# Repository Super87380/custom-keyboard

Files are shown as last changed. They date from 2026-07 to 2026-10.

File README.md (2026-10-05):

# Custom 75% Mechanical Keyboard

This is a custom 75% mechanical keyboard with 3 macro keys that I designed every part for, from the PCB to the firmware.

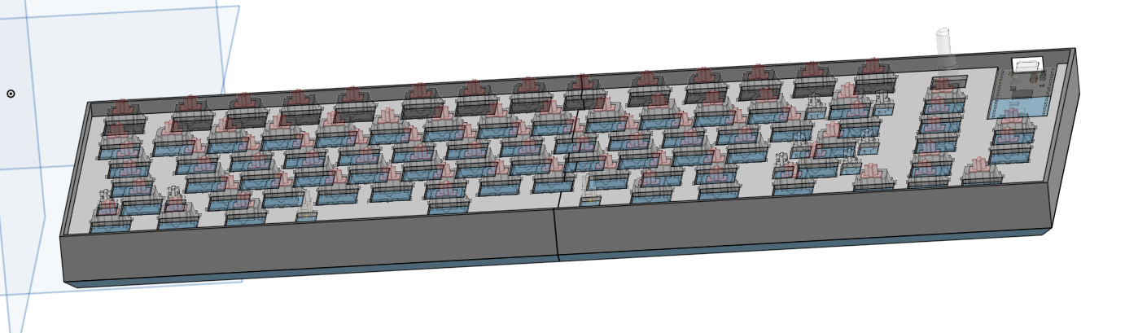
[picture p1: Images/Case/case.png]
Case


## Why I Built it
A while before finding out about Hack Club I wanted to make my own mechanical keyboard. After finding out how much it would cost I got de motivated and gave up on the idea.
Later I was watching YouTube when the creator mentioned Hack Club and how they help teenagers get experience in engineering. I was looking through the programs running when I saw KEEB.
With the opportunity to get the keyboard funded by Hack Club/KEEB it was the perfect chance for me to make the keyboard I had wanted to before.

## Features
- 3 Macro keys
- Rotary Encoder with a switch
- RGB back lighting
- Vast firmware support - the firmware I made uses KMK

## Designing
I started this project by brainstorming ideas for different layouts, sizes, and features. My original idea was a 75% keyboard with a screen, 1 macro key, and a rotary encoder. The idea soon evolved into what it is now.
After brainstorming I used [keyboard layout editor](https://www.keyboard-layout-editor.com/) and [photopea](https://www.photopea.com/) to design the layout and matrix wiring digitally.
I then made the first schematic and PCB in KiCad with a screen and 1 macro key. After I finished the schematic and PCB I realized I wanted to add backlighting for late night gaming/programming sessions and more macro keys, so I added sk6812 mini-e LED's under each switch and removed the screen for 2 more macro keys. After I finished with the electronics I designed a case and plate in Onshape, I found this pretty challenging as it was my first time using Onshape; I can definitely improve the case a lot. I then made the firmware, I chose to sue KMK because I have more expierence with python and have made a macropad with KMK already.

## What I Found Difficult
- LED wiring, especially because I didnt originally route with them in minde
- Modeling the case and plate in Onshape
- Sourcing cheap components with cheap shipping

## What I Learned
- Modelling in Onshape
- Better PCB design
- How mechanical keyboards work
- Reading data sheets and applying what I read
- Layers in KMK
- RGB in KMK




## BOM
| Sl No. | Name | Notes | Quantity | Price Per Unit | Cost | Shipping | Link |
| :---: | :--- | :--- | :---: | :---: | :---: | :---: | :--- |
| 1 | PCB | Manufactured by JLCPBC (minimum 5) (order through JLclone desktop app (saves money)) | 1 | — | $25.40 | $15.96 | [JLCPCB](JLCPCB) |
| 2 | Diode | Diodes to prevent ghosting (part num: 1N41481N4148-T26A) | 84 | $0.0536 | $4.50 | $5.00 | [DigiKey](https://www.digikey.ca/en/products/detail/onsemi/1N4148-T26A/978507) |
| 3 | Resistor | For start and end of LED data signals | 2 | $0.16 | $0.32 | $5.00 | [DigiKey](https://www.digikey.ca/en/products/detail/yageo/RC0805FR-07560RL/728036) |
| 4 | Capacitor | Decoupling capacitors for LED's | 83 | $0.05 | $4.15 | $5.00 | [DigiKey](https://www.digikey.ca/en/products/detail/yageo/CC0603KRX7R7BB104/302822) |
| 5 | LED | LED's for backglow of the keyboard (order in multiples of 5) | 85 | $0.089647 | $7.62 | $15.14 | [LCSC](https://www.lcsc.com/product-detail/C5149201.html?s_z=n_SK6812%2520MINI-E) |
| 6 | Raspberry Pi Pico W (with headers) | The microcontroller for the keyboard (already owned) | 1 | $0.00 | $0.00 | $0.00 | [PiShop](https://www.pishop.ca/product/raspberry-pi-pico-w/) |
| 7 | Switches | Mechanical keyboard switches (pack of 100) | 1 | $26.36 | $26.36 | $0.00 | [Amazon](https://www.amazon.com/dp/B0CX8X1X7P) |
| 8 | Keycaps | Keycaps for the switches | 1 | $14.71 | $14.71 | $0.00 | [AliExpress](https://www.aliexpress.com/item/1005009162201589.html) |
| 9 | Rotary Encoder | Rotary encoder for volume and play/pause media (already owned) | 1 | $0.00 | $0.00 | — | [DigiKey](https://www.digikey.ca/en/products/detail/bourns-inc/PEC11R-4220F-S0012/4499661) |
| 10 | Rotary Encoder Knob | Knob for the rotary encoder, 3D printed | 1 | $0.00 | $0.00 | $0.00 | — |
| 11 | Case + plate | 3D printed | 1 | $0.00 | $0.00 | $0.00 | — |
| 12 | Stabilizers | 7x 2u, 1x 6.25u | 1 | $16.88 | $16.88 | $0.00 | [Walmart](https://www.walmart.ca/en/ip/Mechanical-Keyboard-Cherry-Mx-Switch-Pcb-Mounted-Cherry-Stabilizer-Clear-Transparent-Case-6-25U-Modifier-Key-Stabiliser/7HYKUIE7RG06) |
| 13 | USB C Cable | Aviation style, coiled | 1 | $7.29 | $7.29 | $0.00 | [Amazon](https://www.amazon.ca/Coiled-Keyboards-Aviation-Mechanical-70-87inch/dp/B0GYD7GZT2) |
| 14 | Type C to Micro USB | For connecting the USB C cable to the pico | 1 | $2.49 | $2.49 | $0.00 | [Amazon](https://www.amazon.ca/dp/B0D8ZSWC1D) |

> **Additional Notes:** Items from amazon may have shipping charges, I will use prime so I did not include them in the BOM. All items from digikey have a total shipping cost of $15 CAD, I divded that by 3 to add a shipping price to all of them ($5)
* **Estimated Tax:** $18.70 CAD
* **Total:** $174.52 CAD
* **Total USD:** $125.77 USD

## Files
[PCB](PCB)
[CAD](CAD)
[Firmware](Firmware)
[Journal](JOURNAL.md)
[BOM](BOM)

## Credits
This was made possible through the funding of Hack Club and KEEB, opensource firmware and software, everyone who helped with my questions in the slack, 3D models from grabcad, tutorials on YouTube, and inspiration from other KEEB github repos.

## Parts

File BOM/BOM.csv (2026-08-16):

Sl No. | Name | Notes | Quantity | Price Per unit | Cost | Shipping | Link
1 | PCB | Manufactured by JLCPBC (minimum 5) (order through JLclone desktop app (saves money)) | 1 |  | 25.4 | 15.96 | JLCPCB
2 | Diode | Diodes to prevent ghosting (part num: 1N41481N4148-T26A) | 84 | 0.0536 | 4.5024 | 5 | https://www.digikey.ca/en/products/detail/onsemi/1N4148-T26A/978507?gclsrc=aw.ds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
3 | Resistor | For start and end of LED data signals | 2 | 0.16 | 0.32 | 5 | https://www.digikey.ca/en/products/detail/yageo/RC0805FR-07560RL/728036
4 | Capacitor | Decoupling capacitors for LED's | 83 | 0.05 | 4.15 | 5 | https://www.digikey.ca/en/products/detail/yageo/CC0603KRX7R7BB104/302822
5 | LED | LED's for backglow of the keyboard (order in multiples of 5) | 85 | 0.089647 | 7.62 | 15.14 | https://www.lcsc.com/product-detail/C5149201.html?s_z=n_SK6812%2520MINI-E
6 | Raspberry Pi Pico W (with headers) | The microntroller for the keyboard (already owned) | 1 | 0 | 0 | 0 | https://www.pishop.ca/product/raspberry-pi-pico-w/
7 | Switches | Mechanical keyboard switches (pack of 100) | 1 | 26.36 | 26.36 | 0 | Amazon.com: EPOMAKER Creamy Jade 45gf Gaming Keyboard Switches, 100 PCS Linear Switch, 5-Pin Pre-Lubed Switch, with PC/PA66 Case, POK Stem, Compatible with MX Keycaps for Mechanical Keyboard
8 | Keycaps | Keycaps for the switches | 1 | 14.71 | 14.71 | 0 | https://www.aliexpress.com/item/1005009162201589.html?curPageLogUid=kTwS5RRupty1
9 | Rotary Encoder | Rotary encoder for volume and play/pause media (already owned) | 1 | 0 | 0 |  | https://www.digikey.ca/en/products/detail/bourns-inc/PEC11R-4220F-S0012/4499661?_gl=1*1ggn56e*_up*MQ..*_gs*MQ..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
10 | Rotary Encoder Knob | Knob for the rotary encoder, 3D printed | 1 | 0 | 0 | 0
11 | Case + plate | 3D printed | 1 | 0 | 0 | 0
12 | Stabilzers | 7x 2u, 1x 6.25u | 1 | 16.88 | 16.88 | 0 | https://www.walmart.ca/en/ip/Mechanical-Keyboard-Cherry-Mx-Switch-Pcb-Mounted-Cherry-Stabilizer-Clear-Transparent-Case-6-25U-Modifier-Key-Stabiliser/7HYKUIE7R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
13 | USB C Cable | Aviation style, coiled | 1 | 7.29 | 7.29 | 0 | https://www.amazon.ca/Coiled-Keyboards-Aviation-Mechanical-70-87inch/dp/B0GYD7GZT2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
14 | Type C to Micro USB | For conencting the USB C cable to the pico | 1 | 2.49 | 2.49 | 0 | https://www.amazon.ca/dp/B0D8ZSWC1D
 |  | Additional Notes: Items from amazon may have shipping charges, I have prime so I did not include them in the BOM. All items from digikey shipping total $15 cad, I divded that by 3 to add a shipping price to all of them ($5)
 |  |  |  | Estimated tax: | 18.70
 |  |  |  | Total: | 174.52
 |  |  |  | Total USD: | 125.77

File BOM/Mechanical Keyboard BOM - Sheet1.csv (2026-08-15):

Sl No. | Name | Notes | Quantity | Price Per unit | Cost | Shipping | Link
1 | PCB | Manufactured by JLCPBC (minimum 5) (order through JLclone desktop app (saves money)) | 1 |  | 25.4 | 15.96 | JLCPCB
2 | Diode | Diodes to prevent ghosting (part num: 1N41481N4148-T26A) | 84 | 0.0536 | 4.5024 | 3.75 | https://www.digikey.ca/en/products/detail/onsemi/1N4148-T26A/978507?gclsrc=aw.ds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
3 | Resistor | For start and end of LED data signals | 2 | 0.16 | 0.32 | 3.75 | https://www.digikey.ca/en/products/detail/yageo/RC0805FR-07560RL/728036
4 | Capacitor | Decoupling capacitors for LED's | 83 | 0.05 | 4.15 | 3.75 | https://www.digikey.ca/en/products/detail/yageo/CC0603KRX7R7BB104/302822
5 | LED | LED's for backglow of the keyboard (order in multiples of 5) | 85 | 0.089647 | 7.62 | 15.14 | https://www.lcsc.com/product-detail/C5149201.html?s_z=n_SK6812%2520MINI-E
6 | Raspberry Pi Pico W | The microntroller for the keyboard (already owned) | 1 | 0 | 0 | 0
7 | Switches | Mechanical keyboard switches (pack of 100) | 1 | 26.36 | 26.36 | 0 | Amazon.com: EPOMAKER Creamy Jade 45gf Gaming Keyboard Switches, 100 PCS Linear Switch, 5-Pin Pre-Lubed Switch, with PC/PA66 Case, POK Stem, Compatible with MX Keycaps for Mechanical Keyboard
8 | Keycaps | Keycaps for the switches | 1 | 24.99 | 24.99 | 0 | Shine Through PBT Keycaps - Black Gradient Topographic Side Printed Keycaps Set 133 Keys (60% 65% 75% 100% Full Size, Cherry, Double Shot) RGB Backlit Key Caps for MX Mechanical Gaming Keyboards : Amazon.ca
9 | Rotary Encoder | Rotary encoder for volume and play/pause media | 1 | 3.13 | 3.13 | 3.75 | https://www.digikey.ca/en/products/detail/bourns-inc/PEC11R-4215F-N0012/4699216?gclsrc=aw.ds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
10 | Rotary Encoder Knob | Knob for the rotary encoder, 3D printed | 1 | 0 | 0 | 0
11 | Case + plate | 3D printed | 1 | 0 | 0 | 0
12 | Stabilzers | 4x 2u, 1x 6.5u needed | 1 | 14.99 | 14.99 | 5.49 | Genuine Cherry Clip In Stabilizers — RNDKBD
13 | USB C Cable | Aviation style, coiled | 1 | 7.29 | 7.29 | 0 | https://www.amazon.ca/Coiled-Keyboards-Aviation-Mechanical-70-87inch/dp/B0GYD7GZT2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
14 | Type C to Micro USB | For conencting the USB C cable to the pico | 1 | 2.49 | 2.49 | 0 | https://www.amazon.ca/dp/B0D8ZSWC1D
 |  | Additional Notes: Items from amazon may have shipping charges, I have prime so I did not include them in the BOM. All items from digikey shipping total $15 cad, I divded that by 4 to add a shipping price to all of them (3.75)
 |  |  |  | Estimated tax: | 20.74
 |  |  |  | Total: | 193.57
 |  |  |  | Total USD: | 139.50

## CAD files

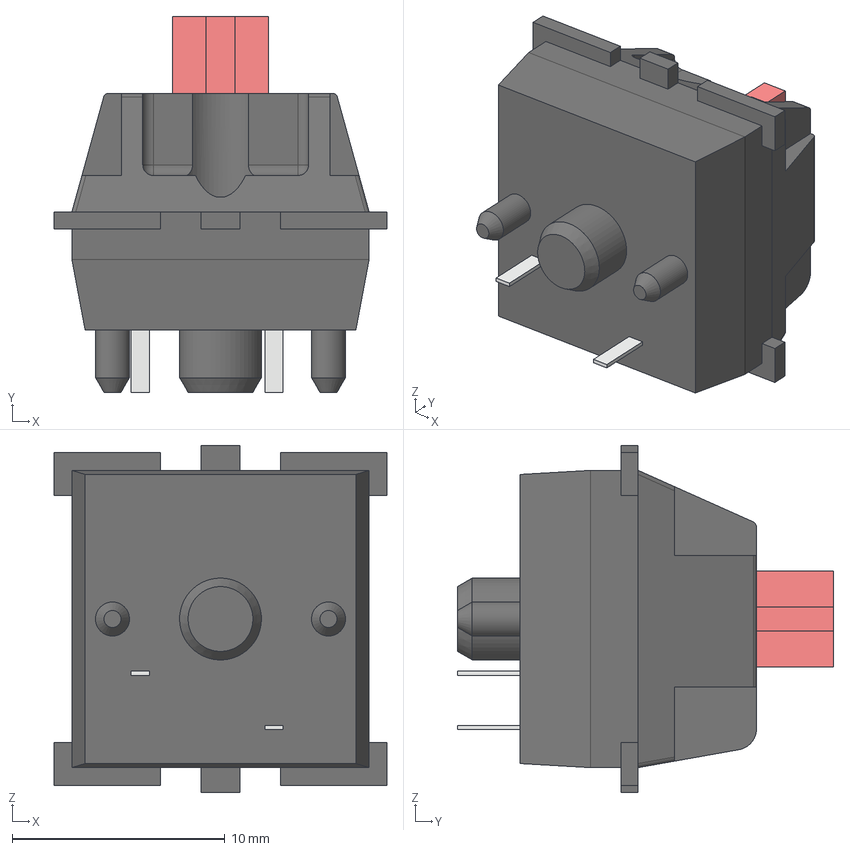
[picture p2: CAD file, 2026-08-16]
PCB/Assets/switch.step
15.6 x 17.7 x 16.3 mm

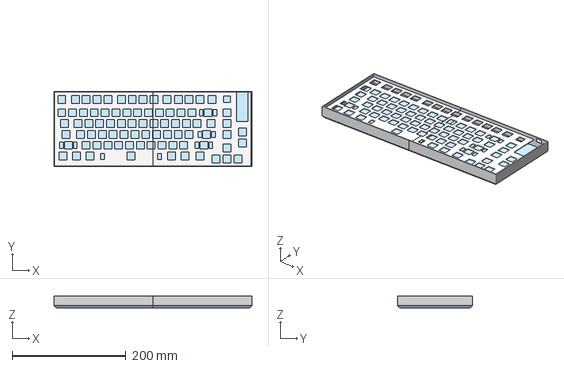
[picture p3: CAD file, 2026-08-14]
Production/Case.step
348.0 x 132.4 x 21.0 mm

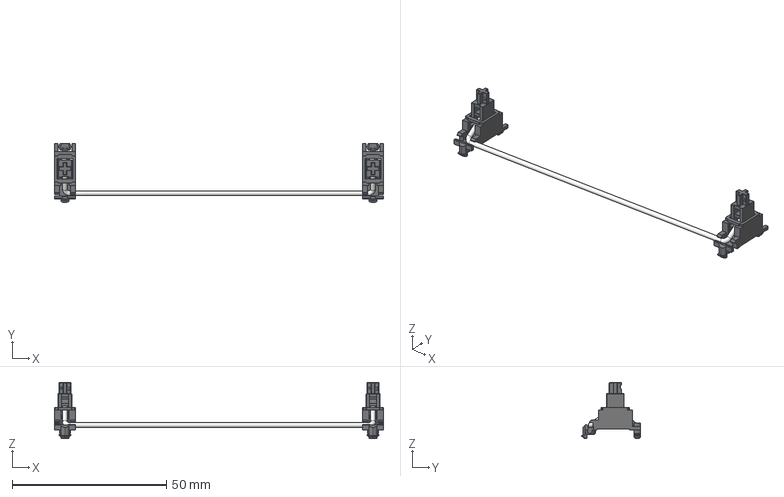
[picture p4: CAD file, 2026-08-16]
PCB/Assets/Stabilizer_Cherry_MX_6.25u.stp
106.8 x 19.2 x 18.3 mm

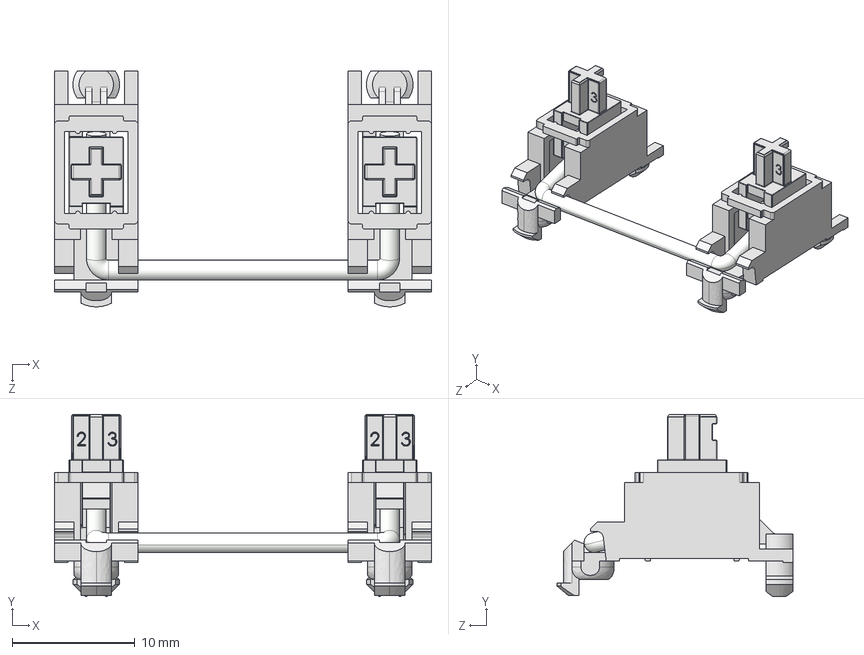
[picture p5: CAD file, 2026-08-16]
PCB/Assets/Stabilizer - close.STEP
30.7 x 14.9 x 19.2 mm
mx Stabilizer base 16828 x 2
mx Stabilizer key 16828 x 2
metal stick 16828

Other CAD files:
CAD/Assets/PCB.step

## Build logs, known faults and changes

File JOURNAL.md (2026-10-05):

---
title: "Custom Mechanical Keyboard"
author: "Super87380"
description: "This is a custom 75% mechanical keyboard that I designed every part for, from the PCB to the firmware. Originally made for KEEB, transferred to Forge."
created_at: "2026-07-03"
---

## July 3: Planning + Design Sketches

#### What I want:
- 75% ish - I've had bigger keyboards and currently have a 100% keyboard and don't find myself ever using the number pad, so I want to create a smaller keyboard
- Not tons of wasted space from microcontrollers and a screen
- I would prefer to have a few macro keys but if I can't fit them in very well i'll just use the macropad I created
- Knob for changing volume and playing/pausing music - I had a keyboard with a volume knob and absolutely loved it!
- Screen for showing volume and current song listening to
- Backlight but I might make the case out of acrylic, in that case I won't use back lights

#### Design 1

**What I like:**
- Not alot of wasted space
- Knob and screen

**What I dont like:**
- No macro keys

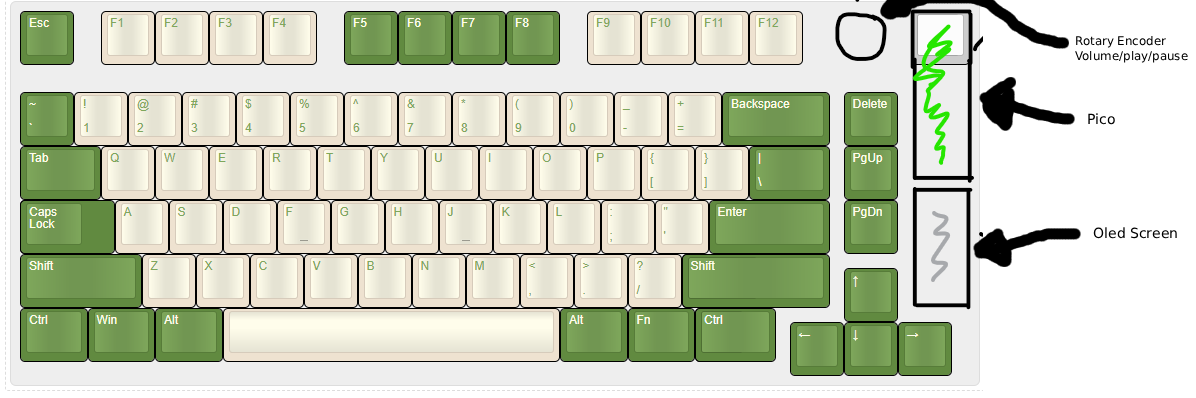
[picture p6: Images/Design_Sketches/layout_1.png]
Layout Design 1


#### Design 2

**What I like:**
- No wasted space
- Plenty of macro keys

**What I dont like:**
- Pico placement - usb cable would get in the way of my mouse
- Too compact (i'd probably accidentally hit the wrong key a few too many times)
- Knob placement - I want it at the top
- No Screen

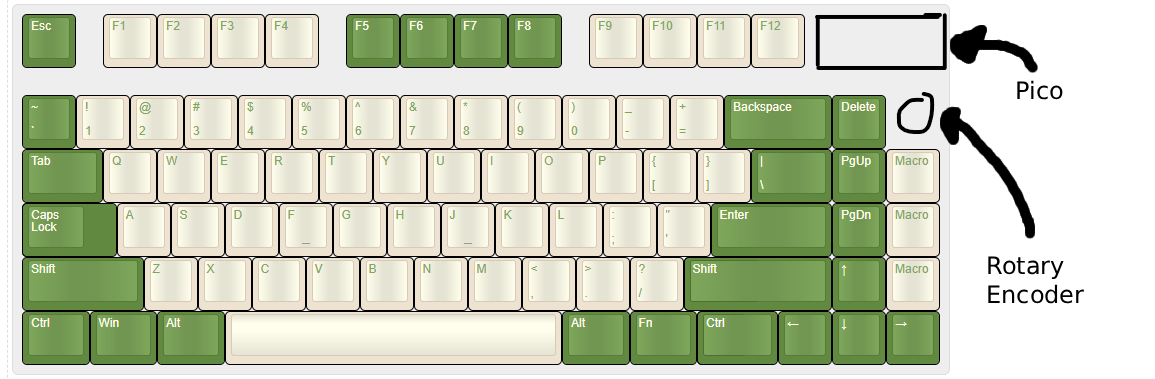
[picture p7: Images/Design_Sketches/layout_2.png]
Layout Design 1


#### Design 3

**What I like:**
- Pico placement
- Screen
- Knob placement
- Plently of macro keys

**What I dont like:**
- A bit of wasted space at the top
- Too compact

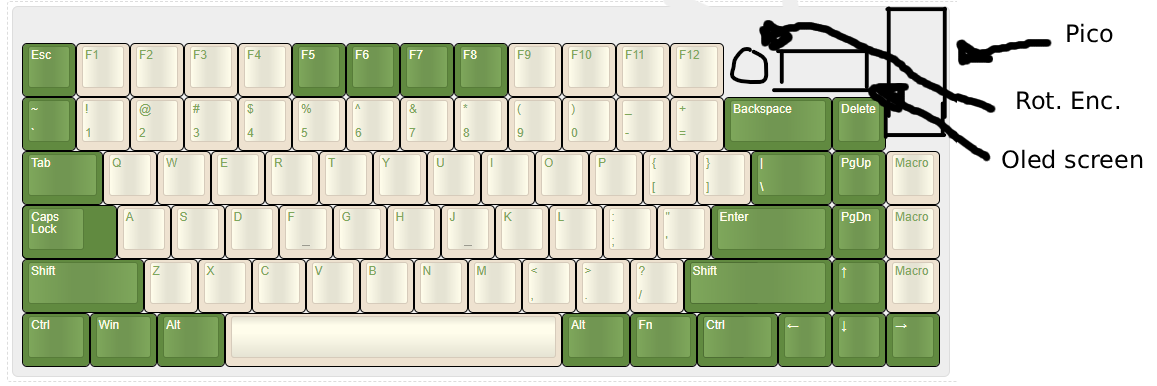
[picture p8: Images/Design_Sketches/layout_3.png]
Layout Design 1


#### Final Design

**What I like:**
- Pico placement - cord won't get in the way of my mouse
- Knob placement - easy to reach quickly and adjust volume
- Screen - Can glance at the screen and see the song i'm listening to
- Very little wasted space (excluding space used to space the keys out more)

**What I dont like**
- Only 1 macro key

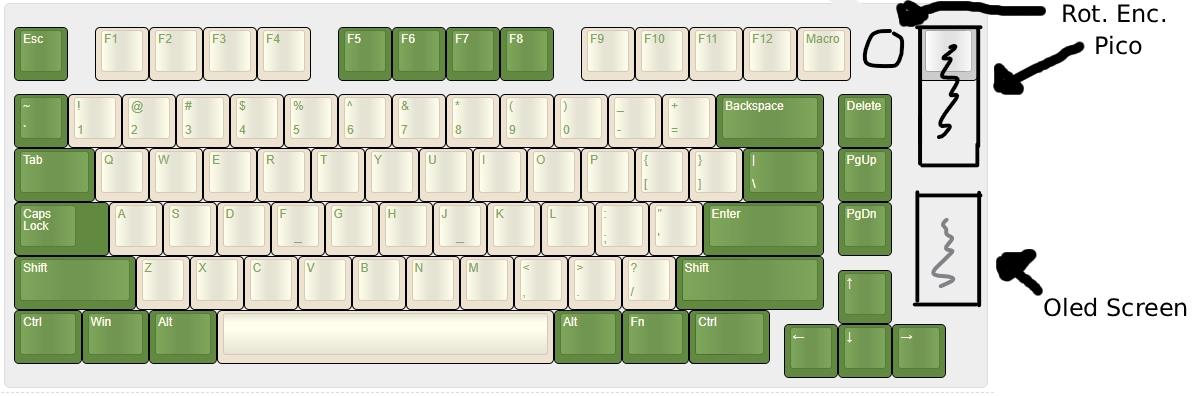
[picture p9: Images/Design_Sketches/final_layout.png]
Layout Design 1


**Total time spent: 1.25 hours**

## July 3 + 4: Making the Schematic

I have used kicad before so I know the basics of how to navigate it but struggled to get the mrbastlib symbols to show for a little even though I had the library installed.
My current design of a 15 * 6 matrix with the rotary encoder and screen doesnt leave many gpio pins available for extra features if I want to add them.
If I decide I want to include led's or another feature i will have to change the layout of my matrix
I want my keyboard to be top mounted, so I didnt add any mounting holes as they wont be needed

#### What I found difficult:
- Getting the marbastlib to work (thanks Neeraj Rajesh on Slack for helping!)
- Wiring the screen (didnt know what SCL and SDA were)

#### What I found easy:
- Placing components
- Wiring the matrix (I've made a macropad with a matrix before)

#### What I learned:
- How to wire a 4 pin oled (GND, VCC, SCL, SDA)
- How to install a library inside of kicad

#### Matrix Wiring
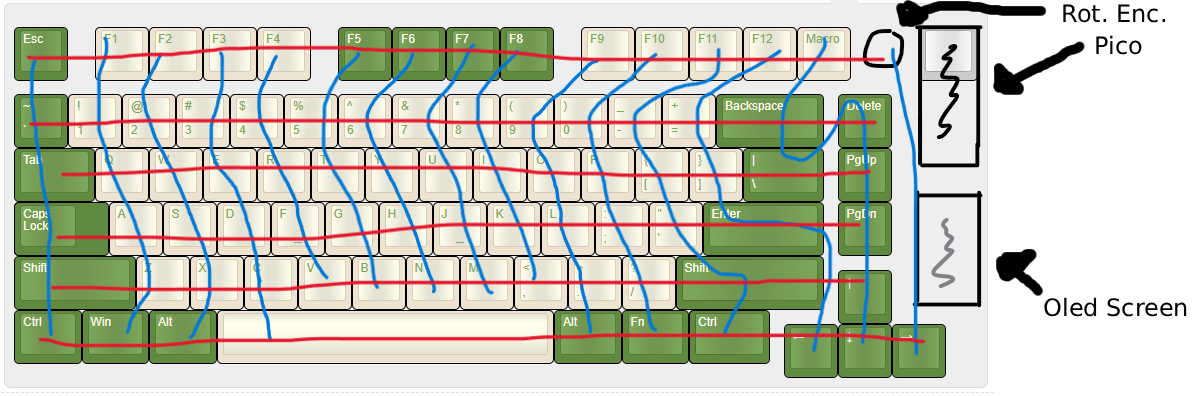
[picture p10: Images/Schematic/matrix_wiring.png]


#### Schematic
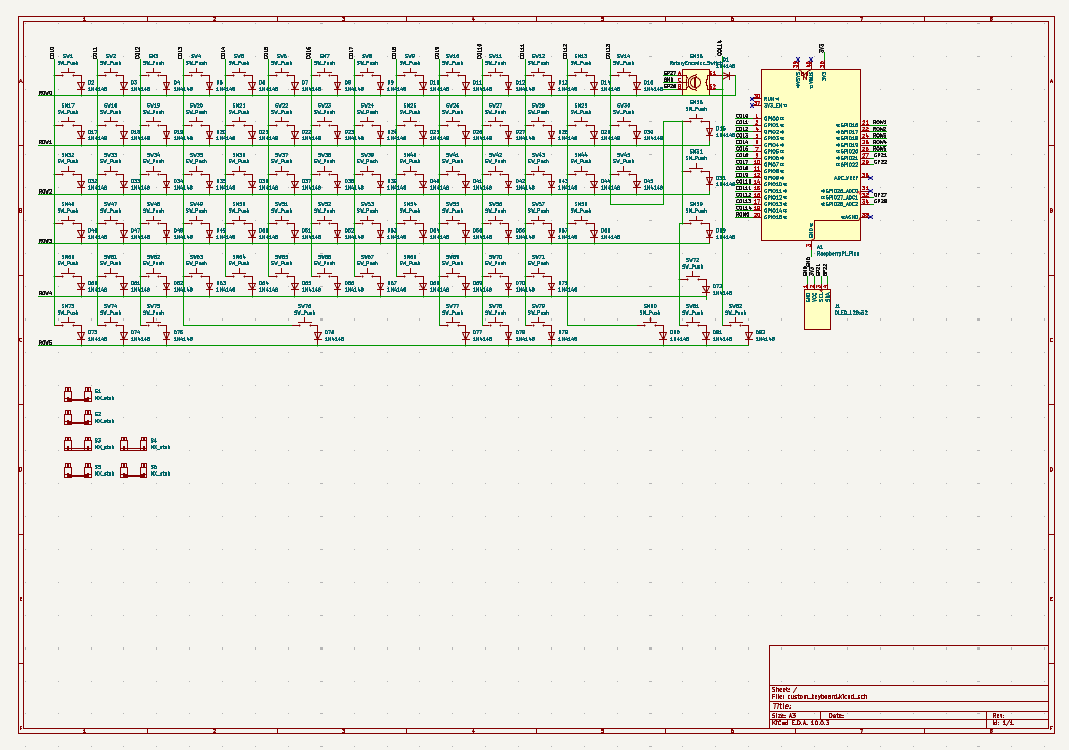
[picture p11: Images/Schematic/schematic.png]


**Total time spent: 1.9 hours**

## July 4 + July 5 + July 6: Making the PCB

<sub><sub>Everything except adding 3d models was done on 04/07/2026.</sub></sub>

Now it's time for the fun part!
I like placing components and designing PCB's because it feels like lego and feels very satisfying when you can finally see your vision in some way or another.

### Making the Rough Key Layout
I started with the rough key layout where I palced the keys roughly where I wanted them and without stabilizers or different key sizes, all 1u.
I did this so that I could get an idea of what I wanted better.
I spent about 0.53 hours on this.

**Rough Switch Placement**
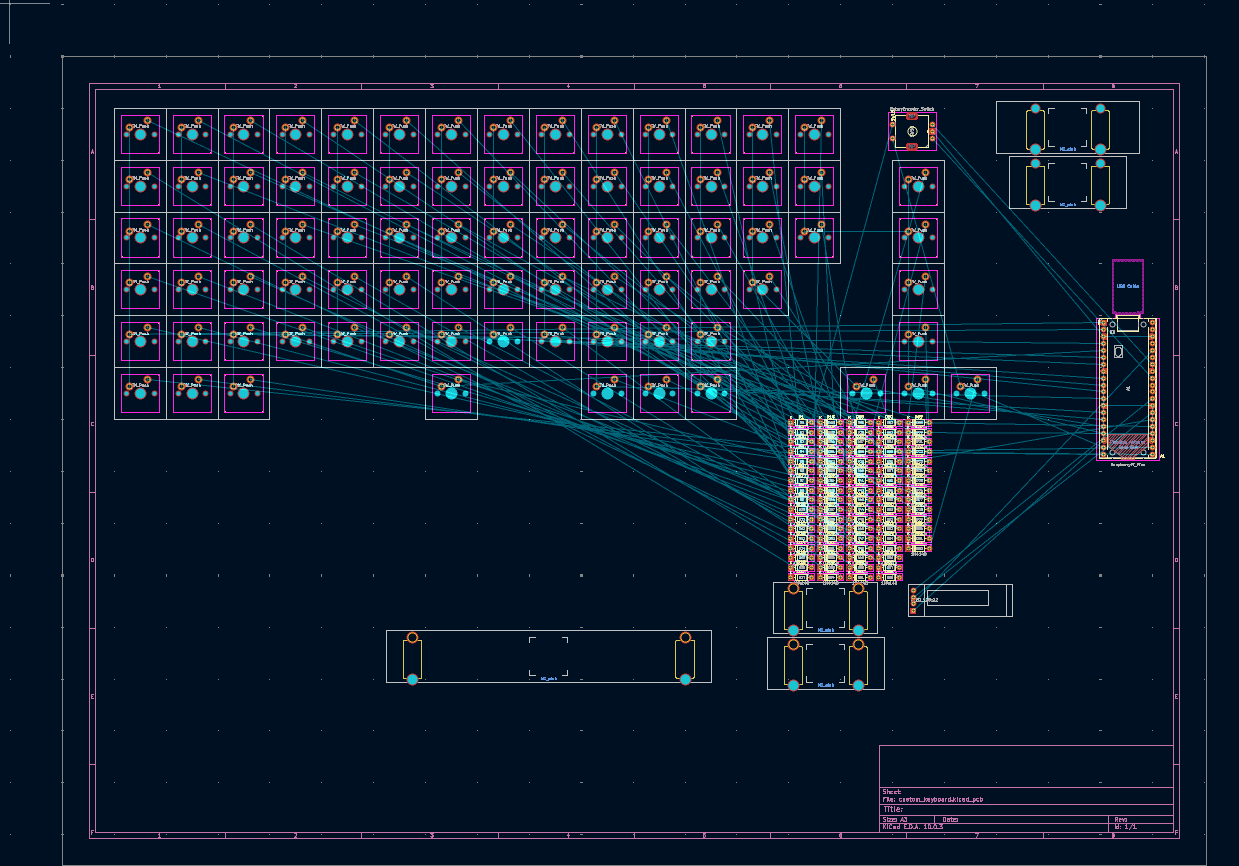
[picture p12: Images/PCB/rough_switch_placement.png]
Rough Switch Placement


### Key placement and Stabilizers
After I finished with the rough layout I added the stabilizers and different key sizes, during this I almost made a slight change to my design.
I moved the function keys over by 0.25u and made the macro key .25u bigger, changing its size from 1u to 1.25u.
I made these changes so that I could center the rotary encoder with the Insert, Delete and End key.
All of this took me 1.2 hours.

**Key Placement**
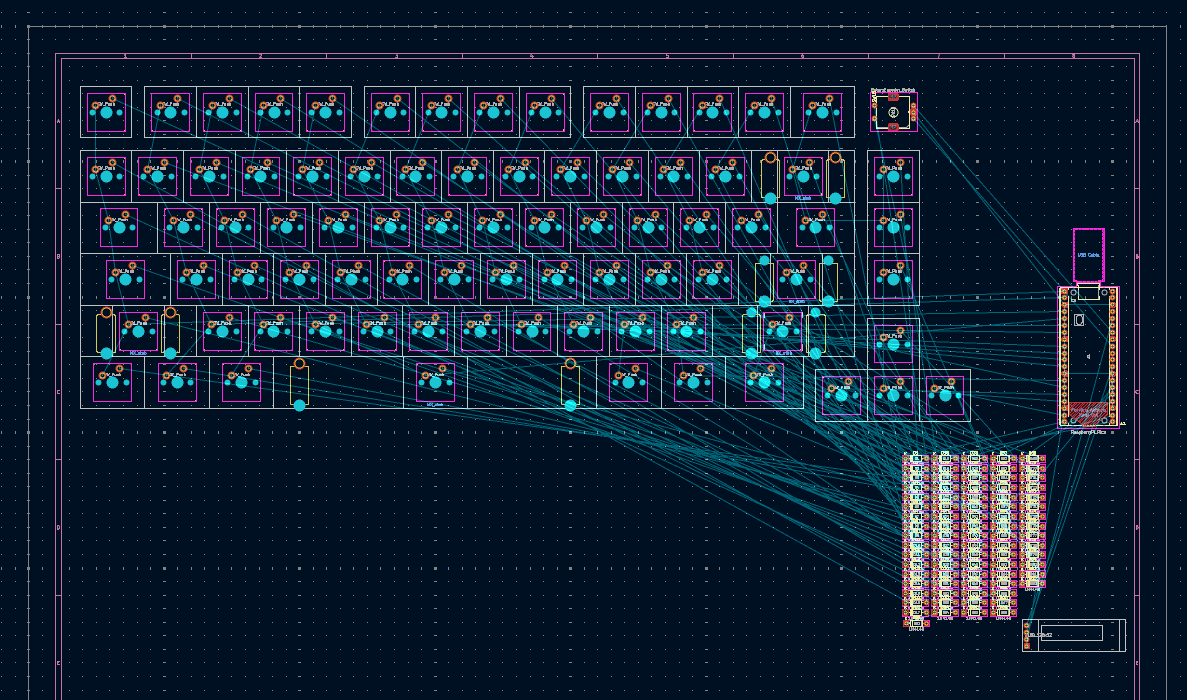
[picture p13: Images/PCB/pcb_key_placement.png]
Key Placement


**Changed Layout Sketch**
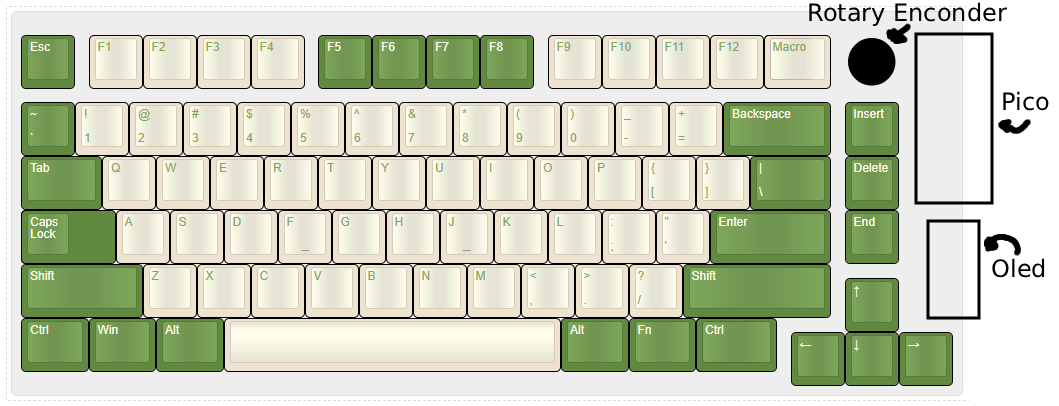
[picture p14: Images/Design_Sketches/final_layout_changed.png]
Changed Layout Sketch


### Placing the Remaining Components
After I finished with the key placing I placed the remaining components:
- Pico
- Diodes
- Screen

This process took me 0.47 hours.
The most time consuming part was placing the diodes.

**PCB After Components Placed**
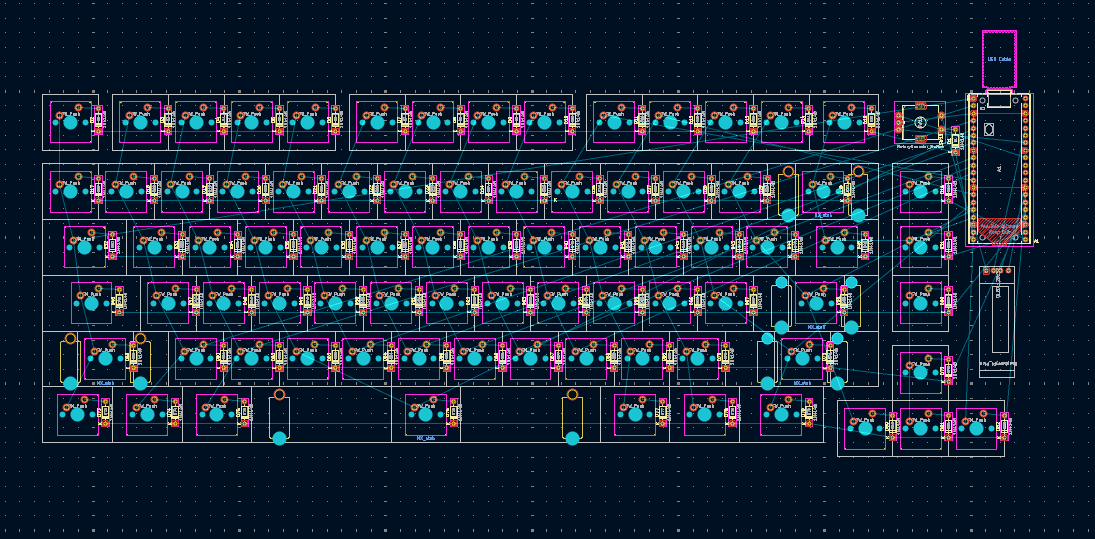
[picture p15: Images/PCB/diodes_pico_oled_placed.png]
PCB After Components Placed


### Wiring Traces
The final step to making my PCB is wiring the traces
I found wiring the traces pretty relaxing especially while listening to music
I also added the edge cut and rounded the edges
I made the silkscreen white and the PCB black
Aswell as those I added a filled zone to isolate the traces from the rest of the copper, it makes the trace more visible aswell.
I spent 1.1 hours doing this

**PCB Without Filled Zones**
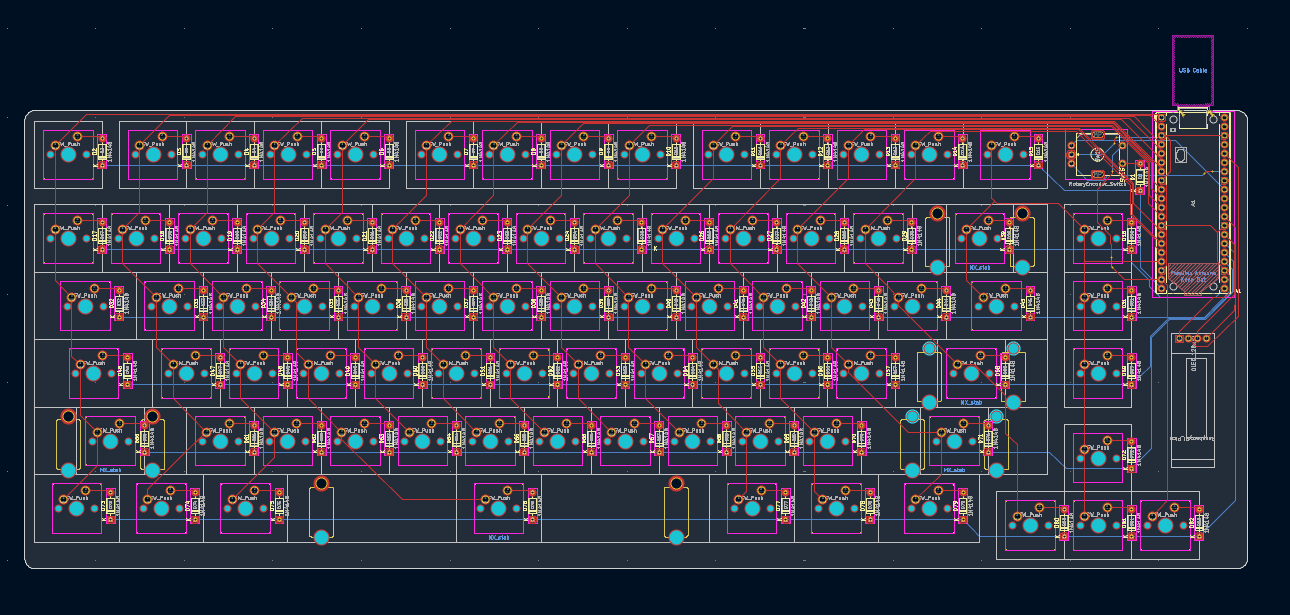
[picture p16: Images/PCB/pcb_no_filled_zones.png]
PCB Without Filled Zones


**PCB With Filled Zone**
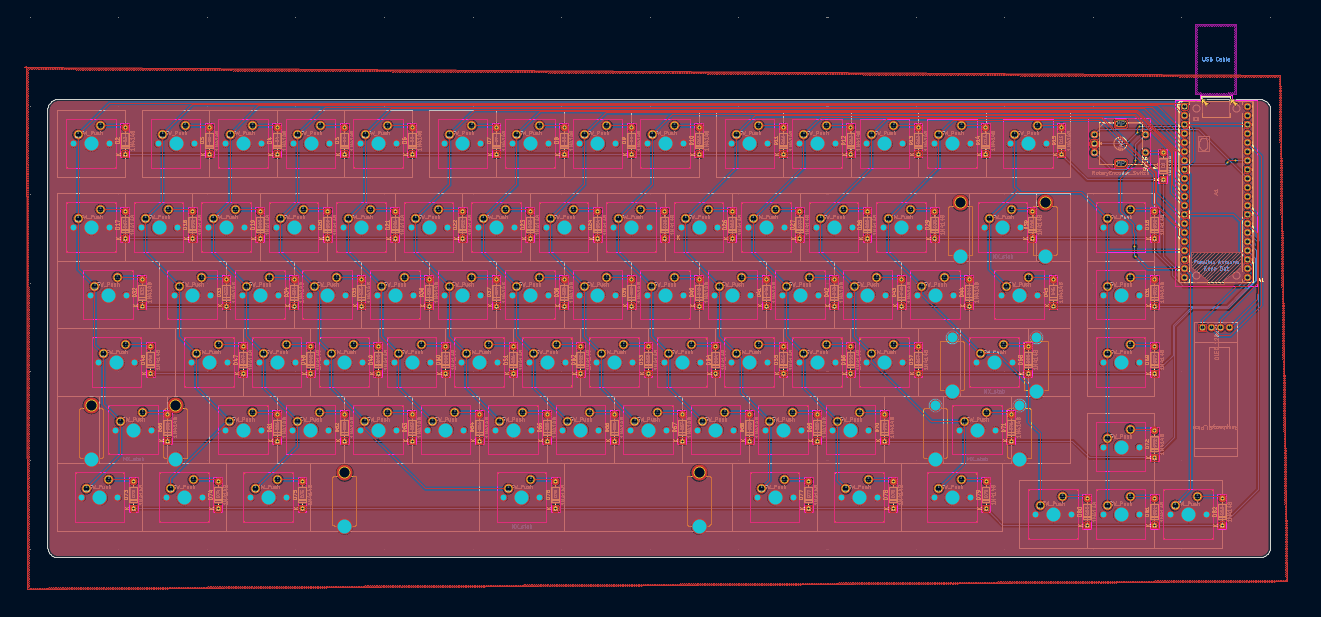
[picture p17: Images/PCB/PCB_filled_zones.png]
PCB With Filled Zones


**PCB Front View**

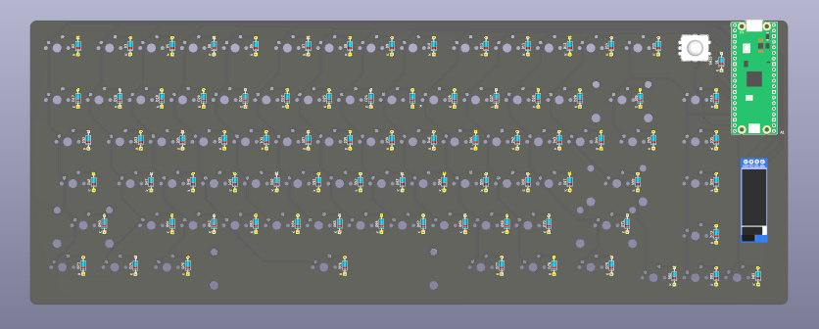
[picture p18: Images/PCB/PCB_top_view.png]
PCB Front View


**PCB Back View**

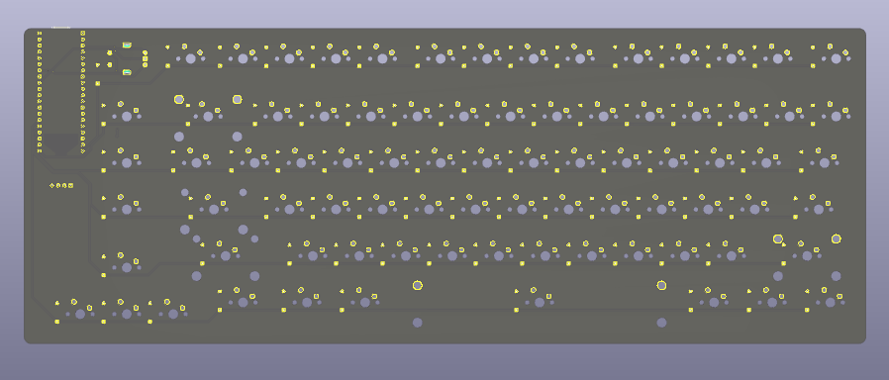
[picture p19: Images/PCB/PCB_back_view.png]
PCB Back View


### Adding 3D Models (05/07/2026 + 06/07/2026)

*Time Spent: 1.3 hours*

#### My struggles:
- Getting the 3d model in the right position
- Finding 3d models

**PCB With Switch and Stabilizer 3D Models**

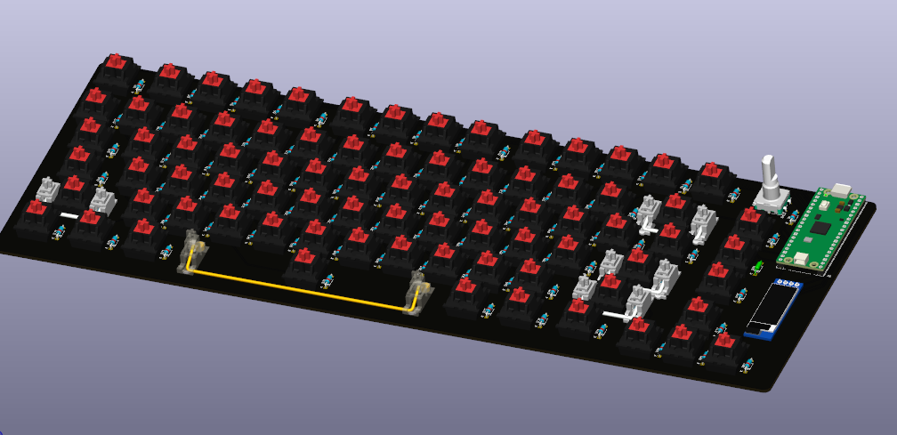
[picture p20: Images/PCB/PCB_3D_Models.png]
PCB With Switch and Stabilizer 3D Models


#### asset links:
2u stabilzer https://grabcad.com/library/cherry-mx-stabilizer-mx-1 \
6.25u stabilzer https://github.com/kiswitch/kiswitch/blob/main/library/3dmodels/3d-library.3dshapes/Stabilizer_Cherry_MX_6.25u.stp \
switch https://github.com/ConstantinoSchillebeeckx/cherry-mx-switch

### Running DRC + Fixing Warnings (06/07/2026)

*Time Spent: 0.15 hours*

I encounterd 5 warnings and 0 errors:
- Track has unconnected end
- Isolated copper fill (2x)
- Silkscreen clipped by board edge (2x)

To fix the track has unconnected end warning I rerouted the part of the trace that wasnt connected
The other warnings I clicked ignore on as I deemed they were not important and would not affect the board in any negative way other than a tiny part of the pico silkscreen being cut off but it was not important

**DRC Before Fixing**

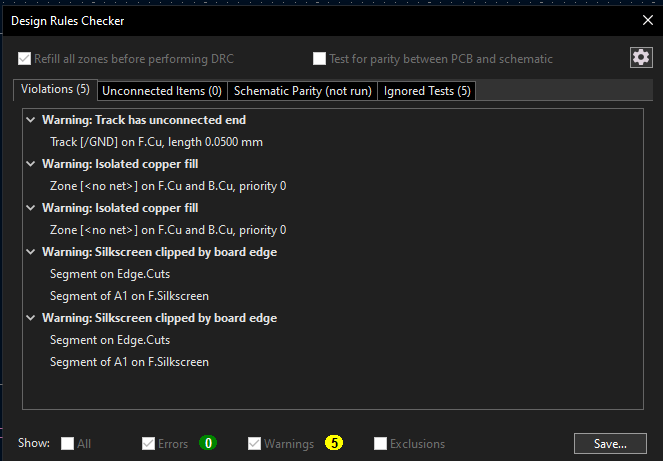
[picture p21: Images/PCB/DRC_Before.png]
DRC Before Fixing


**DRC After Fixing**

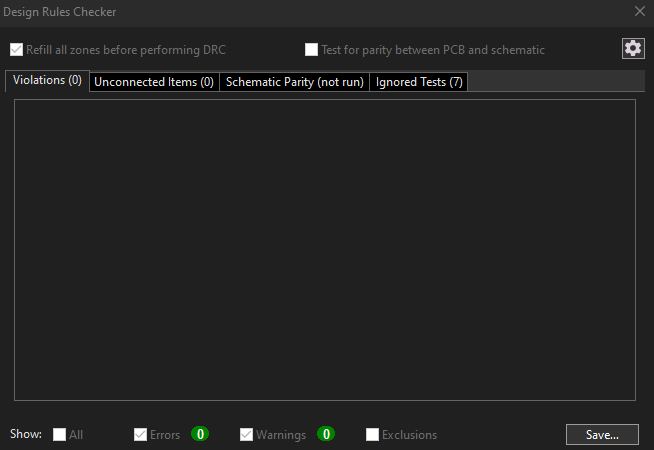
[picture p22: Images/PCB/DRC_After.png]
DRC After Fixing


**Total time spent: 4.75 hours**

## July 7: Designing the Silk Screen

Added some pictures and text to the front and back silk screen and outline to board
Tutorial Used: https://www.youtube.com/watch?v=JVZk_96jJsI

**Front Silkscreen**
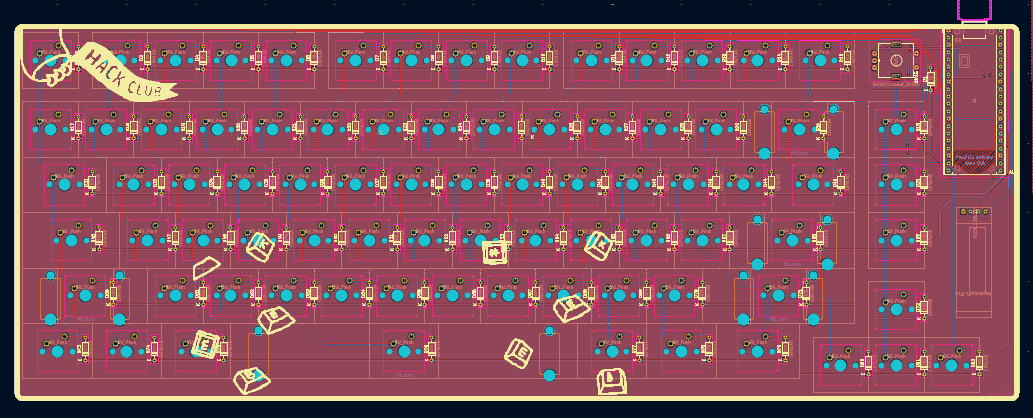
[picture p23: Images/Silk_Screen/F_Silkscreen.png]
Front Silkscreen


**Front Silkscreen 3D**
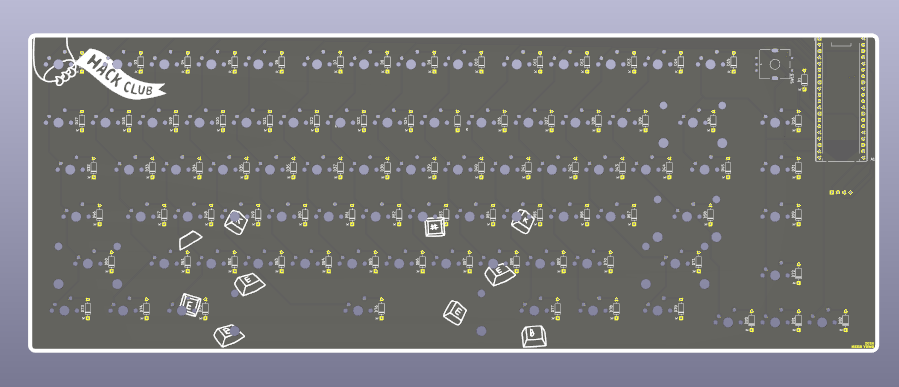
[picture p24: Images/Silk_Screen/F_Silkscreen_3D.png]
Front Silkscreen 3D


**Total time spent: 0.58 hours**

## July 7 + July 8: Making Changes

I decided I didn't want the screen and replaced it with 2 extra macro keys
I also added SK6812MINI-E LEDS and M3 mounting holes

I started by making the changes to the schematic, I deleted the screen then added the led and wired them, I used [the data sheet](https://www.lcsc.com/datasheet/C5149201.pdf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) to figure out what goes where.
I struggled with keeping the schematic organized

**LED Array Schematic**

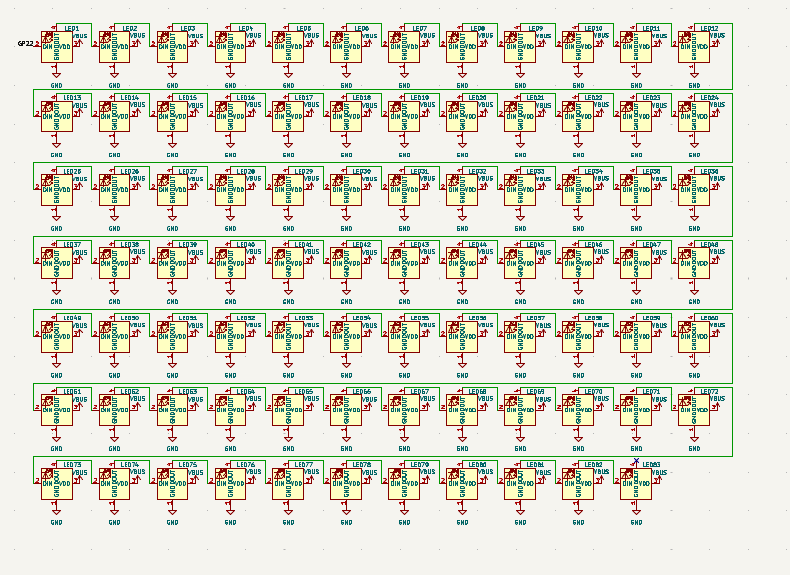
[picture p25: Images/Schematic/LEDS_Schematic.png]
LED Array Schematic
  

After I finished with the schematic I updated the PCB and started placing the LEDS aligned to the center and at the bottom of each switch, this process was very tedious and time consuming.

**LED's and Extra Macros Placed**
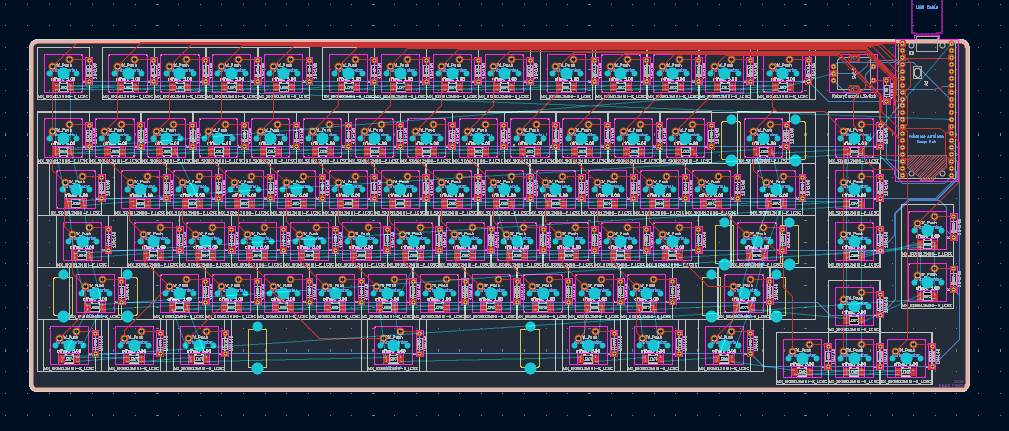
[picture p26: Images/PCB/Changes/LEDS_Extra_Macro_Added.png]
LED's and Extra Macros Placed


Once I placed the LEDS I realized I was going to need to reroute all the traces on the Front Copper Layer in order to have them wired neatly.

**Front Copper Traces Removed**
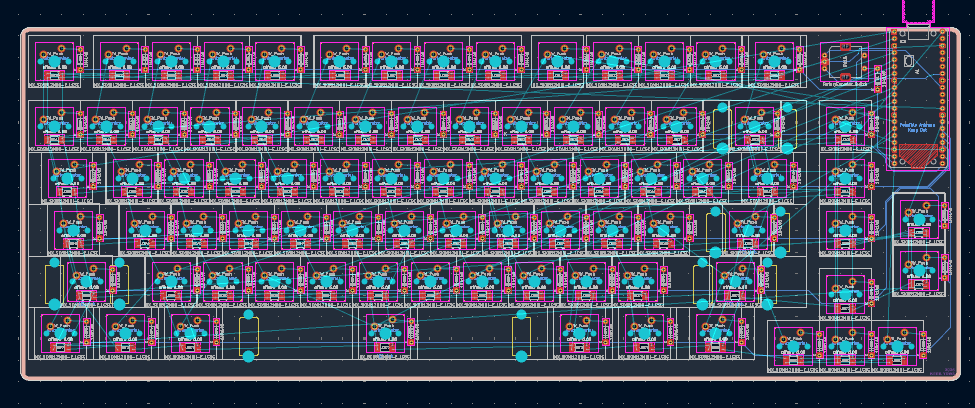
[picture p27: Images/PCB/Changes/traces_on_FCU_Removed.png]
Front Copper Traces Removed


After I removed the Front Copper Layer traces I started wiring the DIN and DOUT pads of the leds, after that I wired the VDD to the VBUS of the pico.
I found wiring the Power particulary challenging as the traces have to be much bigger than the other ones so I had to make space.
I then re routed the coloumns

**Traces Routed**
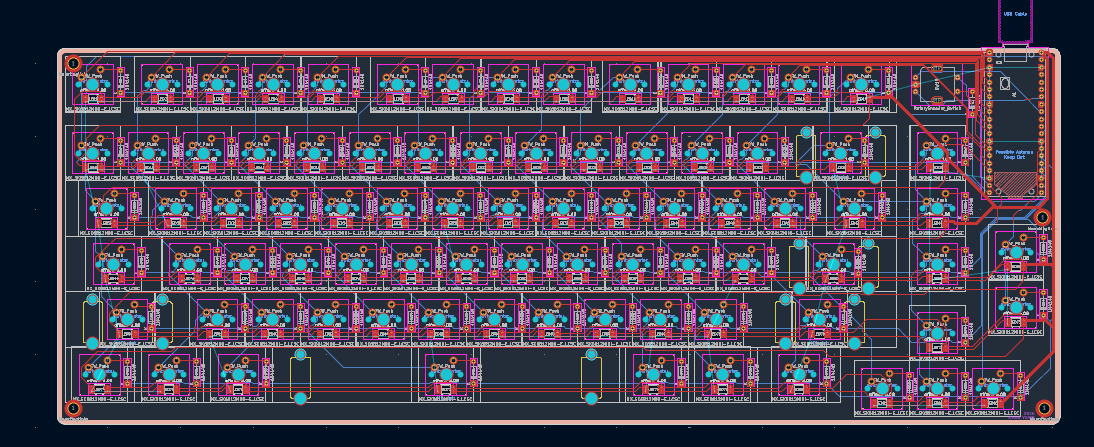
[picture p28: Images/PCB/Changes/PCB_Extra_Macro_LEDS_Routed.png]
Traces Routed


**New Layout**
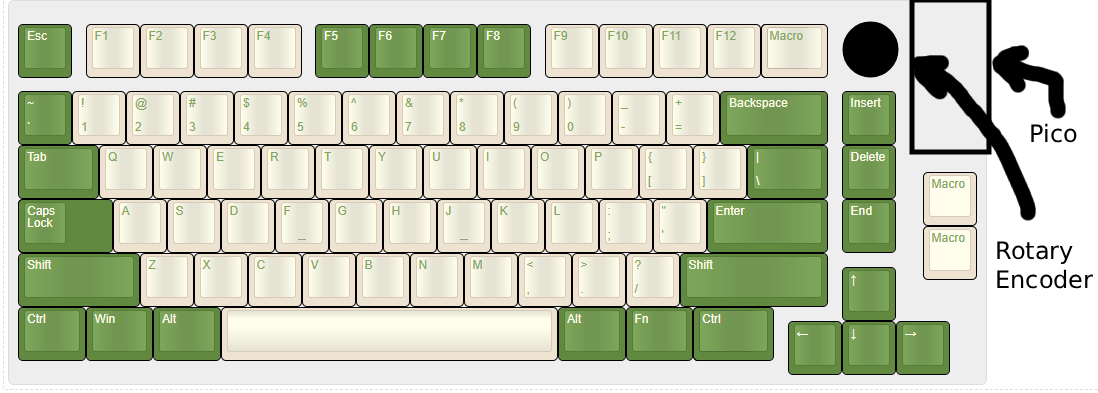
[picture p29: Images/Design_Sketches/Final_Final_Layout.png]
New Layout


**Total time spent: 2.7 hours**

## July 8 + July 9: Running DRC + Fixing Errors and Warnings

After I finished routing all the led's and colunms I ran the DRC
Lets just say, the results of the DRC are not what I wanted or expected, I expected some errors because i've never routed led matrix's but i though only a few, not **384** and **105** warnings 😬

**Not Good**
Not Good

The most prominent error was: Board edge clearance violation

Board Edge Clearance Violation

A majority of these came from the led's pads being too close to the edge cut of the led
to fix this I moved the pads slightly over and decreased the board edge clearance restraint in *File/Board Setup/Design Rules/Constraints*. The amount I changed it to is still well within the manufacture I plan to use (JLCPCB) abilities.
Although a lot of the Board Edge Clearance Violations came from the pads being to close to the edge cuts quite a few also came from the row traces being to close to the LED edge cuts, I fixed those by moving the trace up slightly.

The second large amount of errors I encountered were from the courtyards of thew switches and LED's overlapping.
I looked at the sizes of the components in the 3d viewer and data sheet and concluded that the courtyards overlapping would not be a problem so I simply ignored those errors.

I also moved the silk screen borders to avoid touching the mounting holes (had a warning for that)

I have alot of warnings still for silk screen clearance (silk screen touching other silkscreen or over an edge cut)
I believe when I export the Gerbers I can make it clip those automatically, if not I will fix them.

I also realized I forgot to wire the grounds of the LED's
I created a ground plane to wire them easily

**Finished PCB**
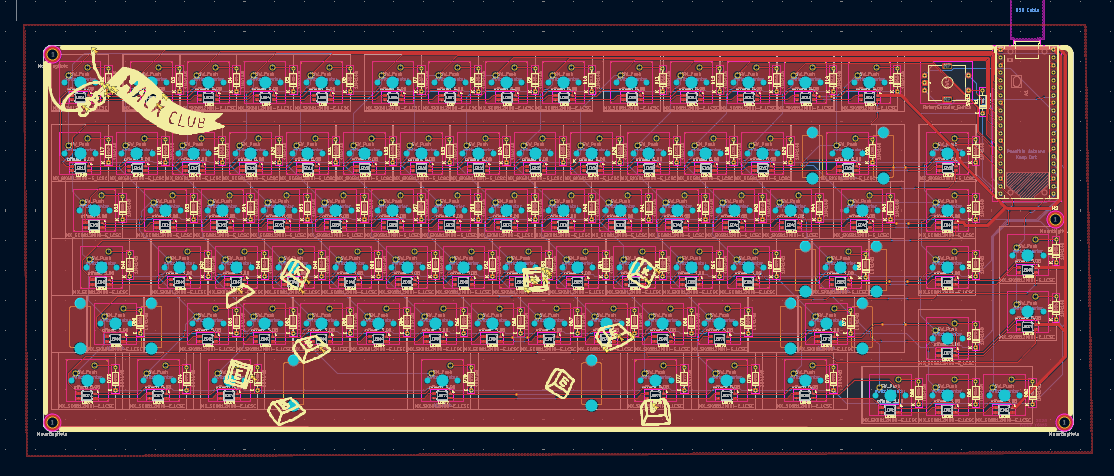
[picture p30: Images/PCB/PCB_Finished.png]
Finished PCB


**Finished PCB 3D**
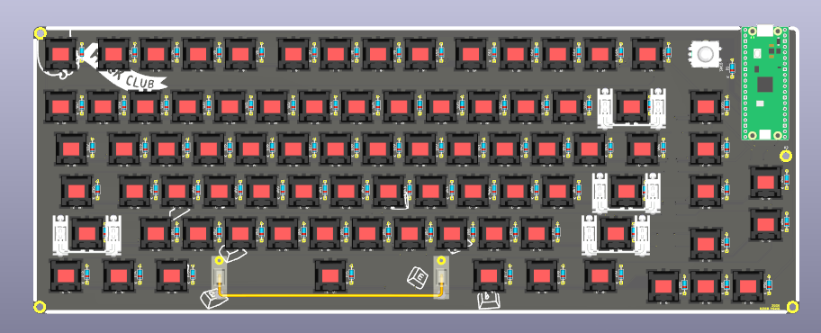
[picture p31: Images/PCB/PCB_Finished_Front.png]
Finished PCB 3D


**Total time spent: 1.75 hours**

## July 24 + August 8: Making the Case

The case took me way longer than I would've wished because it was my first time using onshape and I struggled a lot doing the most basic of things. 
The progress is spread over many days doing a tiny bit of work each day.

#### What I found difficult:
- Learning how to navigate onshape
- Learning the different tools and features of onshape
- Fixing import errors
- Extruding with remove

#### What I found easy:
- Downloading the pcb model from kicad 😭

#### What I learned:
- How to make a sketch in onshape
- How to extrude in onshape (and different extruding ways)
- How to make a chamfer

### Importing the PCB 3d model and making the base
I started by importing the PCB 3d model and making the base of the case
When importing the PCB model I encountered problems with it not loading correctly

**Case Base**
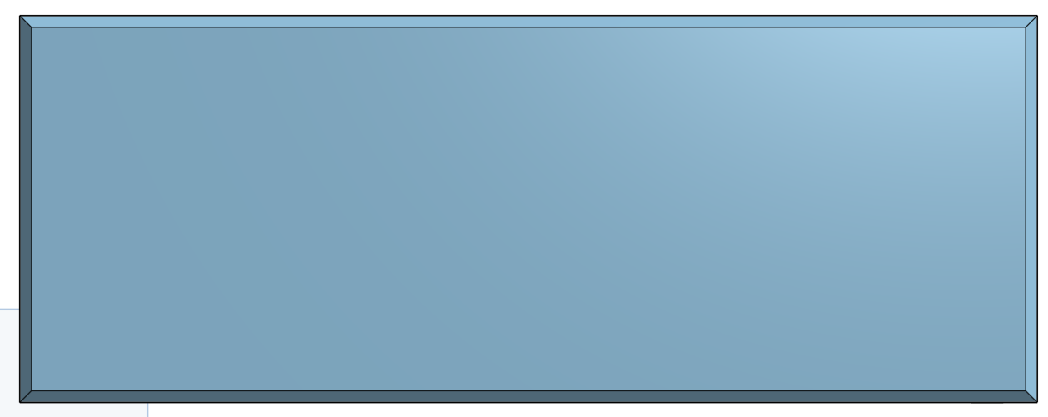
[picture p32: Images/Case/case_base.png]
Case Base


### Adding walls and making the plate
I then added walls and made the plate that the keys go on.
I found it time consuming to place the key holes even with the linear pattern tool. (more screenshots of creating the plate and tools used in Images/Case)

**Case Walls**
Case Walls
**Case Plate**
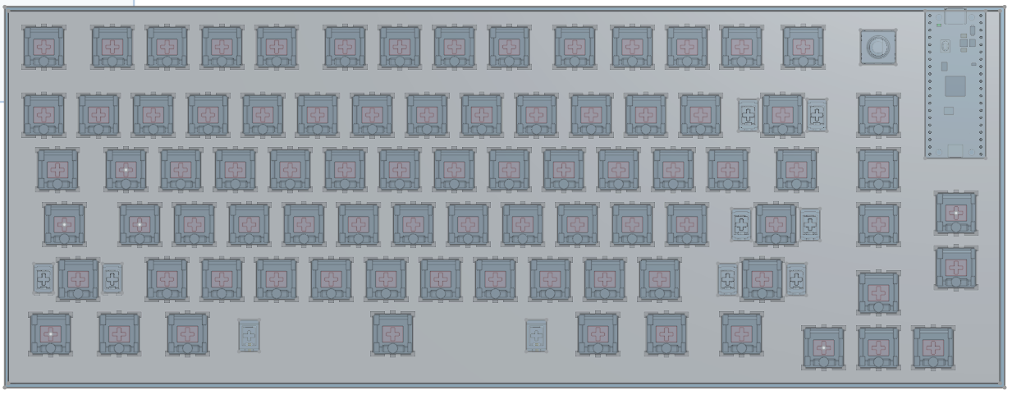
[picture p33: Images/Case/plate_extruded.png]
Case Plate


### USB port
After I made the walls and plate I cut a hole in the wall so you can access the usb port on the raspberry pi pico.

**USB Port Cutout**

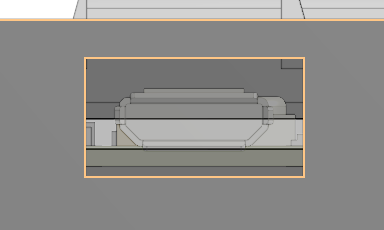
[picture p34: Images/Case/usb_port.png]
Case Base


### Splitting and making alignment pillars
After all of that I split the case into 2 segments and added alignment pillars so I can connect them together easily once 3d printed

**Split and alignment**
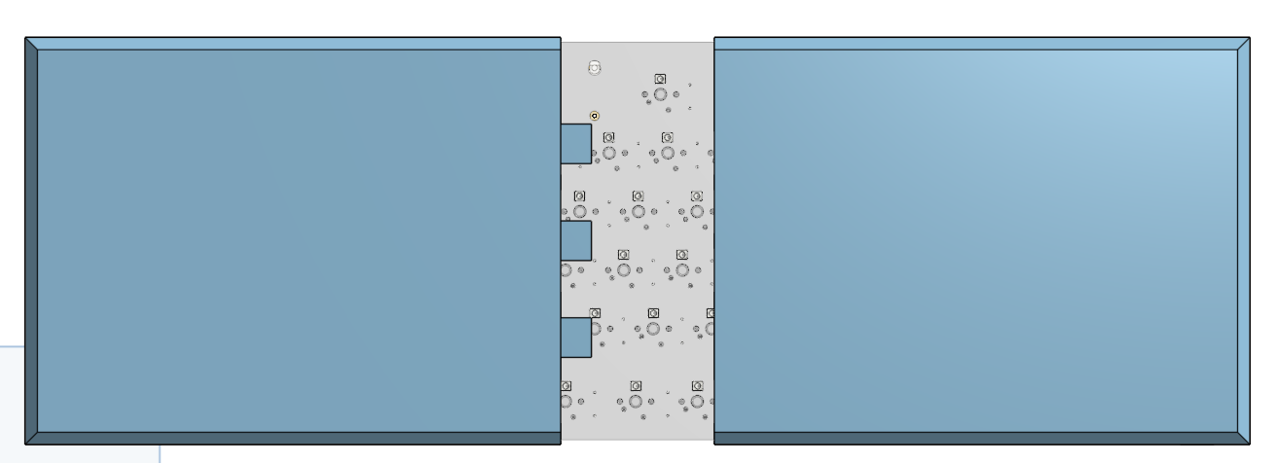
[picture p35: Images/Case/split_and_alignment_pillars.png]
Spilt and alignment


I may make minor changes to the case after submitting

**Total time spent: 3.23 hours**

## August 8 + August 10 + August 12: Fixing the PCB

I started by looking at the datasheet and noticed my pin locations on the footprint where wrong and on the wrong copper layer for reverse mount (placed on bottom copper layer with hole in pcb that allows light to shine to the key)

**Old Footprint**

Old Footprint

**Updated Footprint**

Old Footprint

After I fixed the footprint I got started on adding the capacitors and resistors to the schematic

**Fixed LED Matrix Schematic**

Fixed LED Matrix Schematic

After doing the schematic I moved onto the PCB, I started by removing the old LED's and traces for them and then adding the new LED's along with a capacitor for each one, I then placed the resistors at the first and last data pin of the led matrix. The next step I took was cleaning up and moving some of the column traces as they would get in the way of the LED power and data traces and it would be much easier to move those than trying to work around them with the LED traces in an already crowded area. I then wired the VBUS to one side of each capacitor and to the VDD pad of each LED as well (Decoupling capacitors). I then did the data traces. After doing all those traces I decided to add a GND plane to the back copper layer as well, not just the front. I did this because The LED's on each LED required 2 GNDS (including capacitor and GND pad) and it would be way easier to connect them that way. I already had a front copper layer so via stitching was easy. I also cleaned up the silk screen a bit.

**Fixed PCB**

Fixed PCB

**Total time spent: 3.82 hours**

## August 13: Writing the Firmware

I decided to use KMK instead of RMK as I am more familiar with Python and found more tutorials available for KMK.
To make the firmware I watched [this playlist/tutorial by Tiny Boat Productions](https://youtube.com/playlist?list=PLtl-yze0Zzkm5n2ajJRUL48EyCyUgsXf6&si=secS5v1txR7g7JIm) on YouTube and used the [KMK docs on github](https://github.com/KMKfw/kmk_firmware/tree/main/docs/en)

I started off by defining the rows and columns then creating the keymap according to [my layout](../Images/Design_Sketches/Final_Final_Layout.png)
I Then added a save, calculator, and screenshot macro.
After I made the macros I Added the RGB LED's and a seperate layer for keys to change aspects about the LED's.
I set the max brightness of the LED's to 60 (max 255) and default to 40 to protect from power surges, I will increase/decrease once the keyboard is built and I can test them out.
I then added the rotary encoder and made it change the volume

**It is important to note you must have [circuitPy](https://circuitpython.org/) and [KMK](https://github.com/KMKfw/kmk_firmware) installed onto the pico for the code to work.**\
Macro snippet\


**Total time spent: 0.79 hours**

## August 13 + August 14 + August 15: Making the BOM

This includes researching parts, generating quotes, and making the Bill of Materials

I struggled trying to find good places for components that were affordable and had good shipping. Often I would find a part thats cheap but then the shipping would be insanely high, so I tried to find a balance of good price and good shipping.
Which led me to using amazon for quite a few parts because I have amazon prime.
I also found out that If you download the JLClone desktop app (JLCPCB desktop app) that you can get pcb manufacturing and shipping for substantially cheaper.


**Total time spent: 1.4 hours**

## August 15: Writing the README
I took some time to look at other peoples README's for inspiration and to write my own including what I learnt, features, why I built it, and more.\


**Total time spent: 0.63 hours**

## October 4: Transferred to Forge

I transferred the project to Forge as I submitted for review on KEEB almost 2 months ago and didn't hear anything back and the program has now ended.
I had to merge all my separate journals into one JOURNAL.md file.
Cleaned up the repo, updated the README with more images, added the BOM (used Gemini to convert my BOM.csv into a md table) and fixed some typos I saw.
Added the PCB file to the PCB folder, I forgot to before.



**Total time spent: 1 hour**

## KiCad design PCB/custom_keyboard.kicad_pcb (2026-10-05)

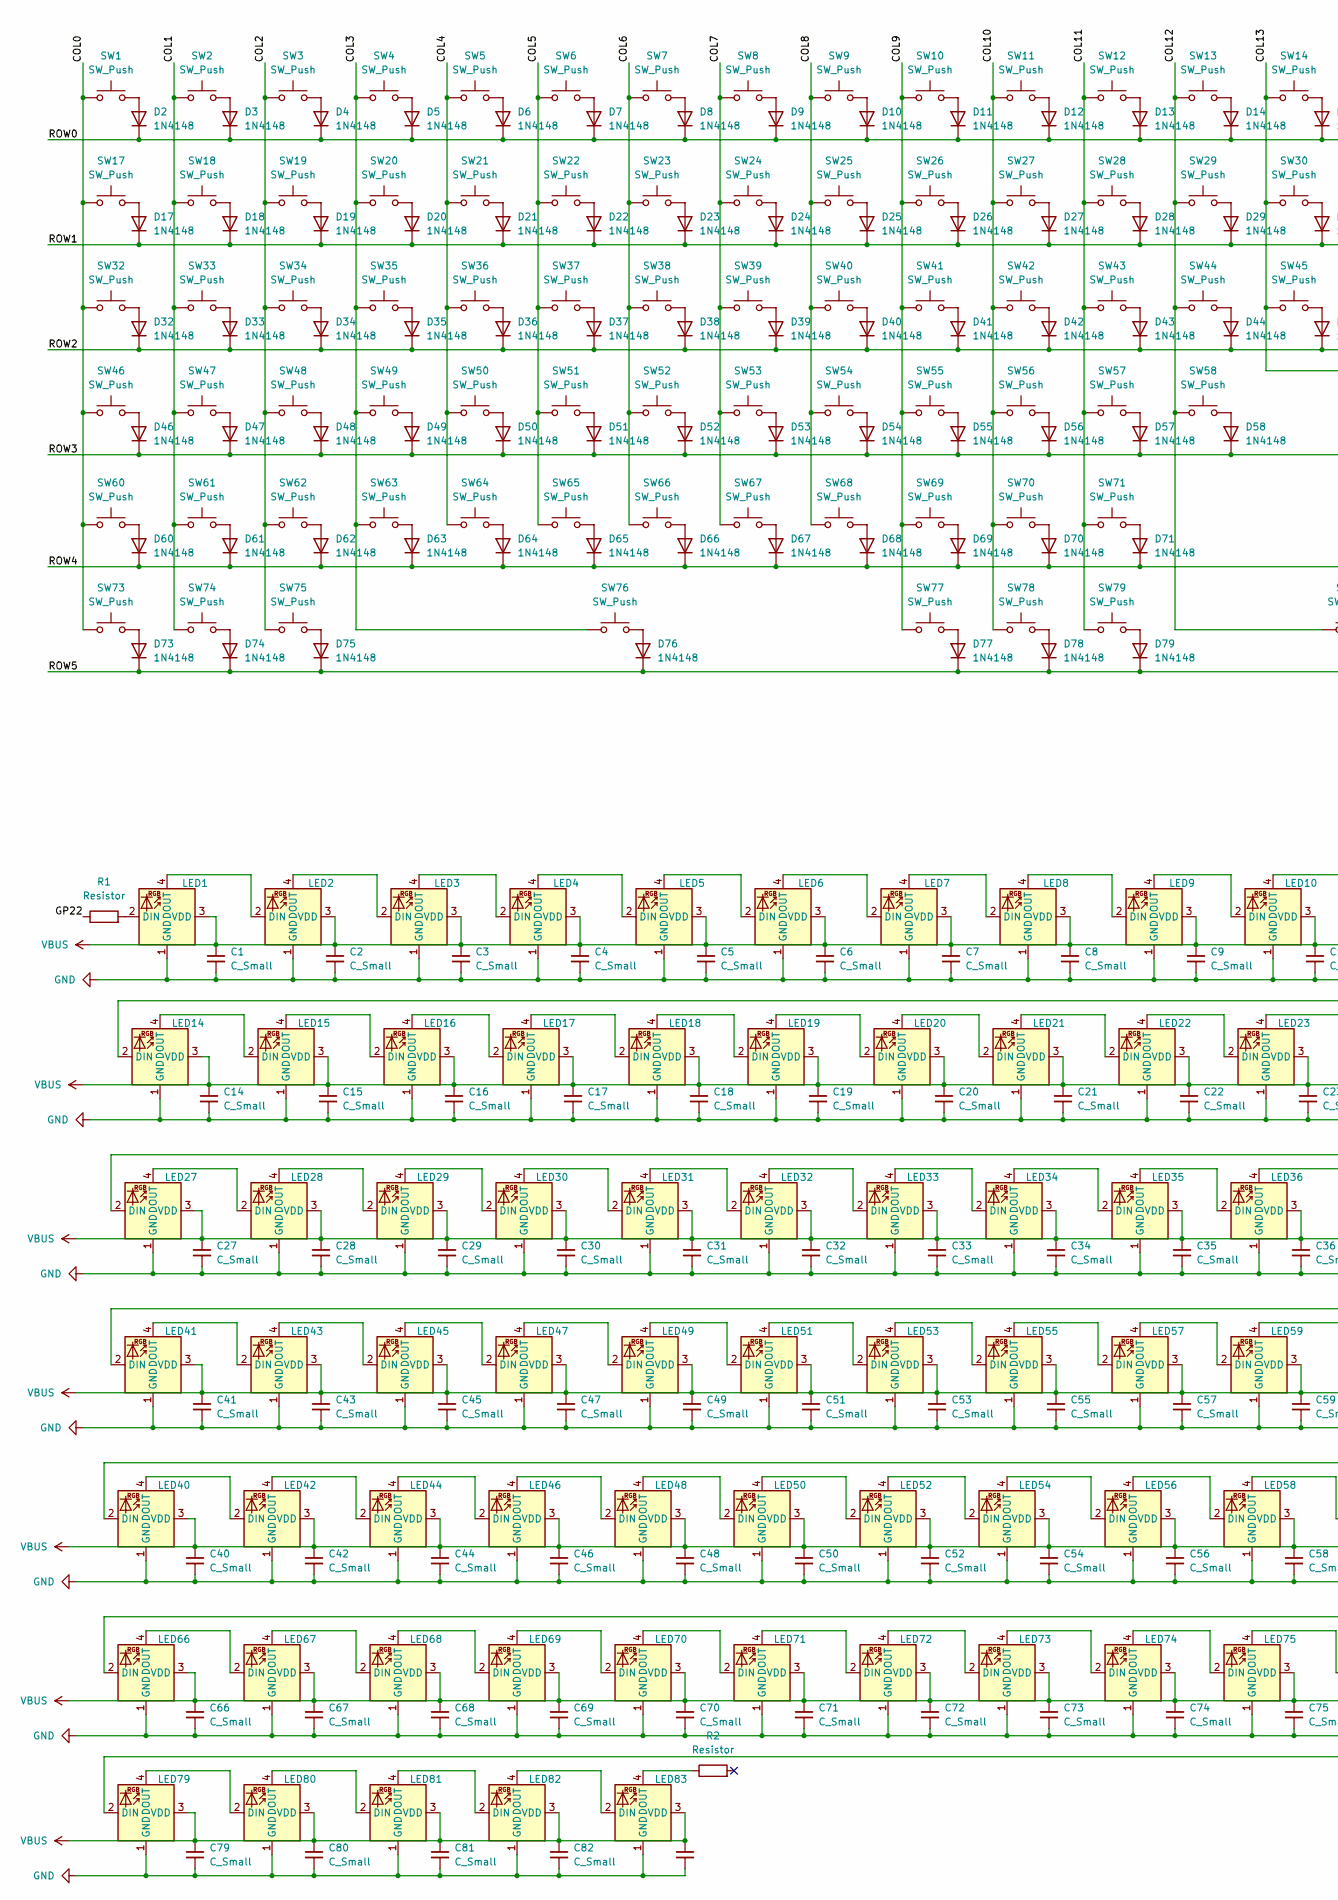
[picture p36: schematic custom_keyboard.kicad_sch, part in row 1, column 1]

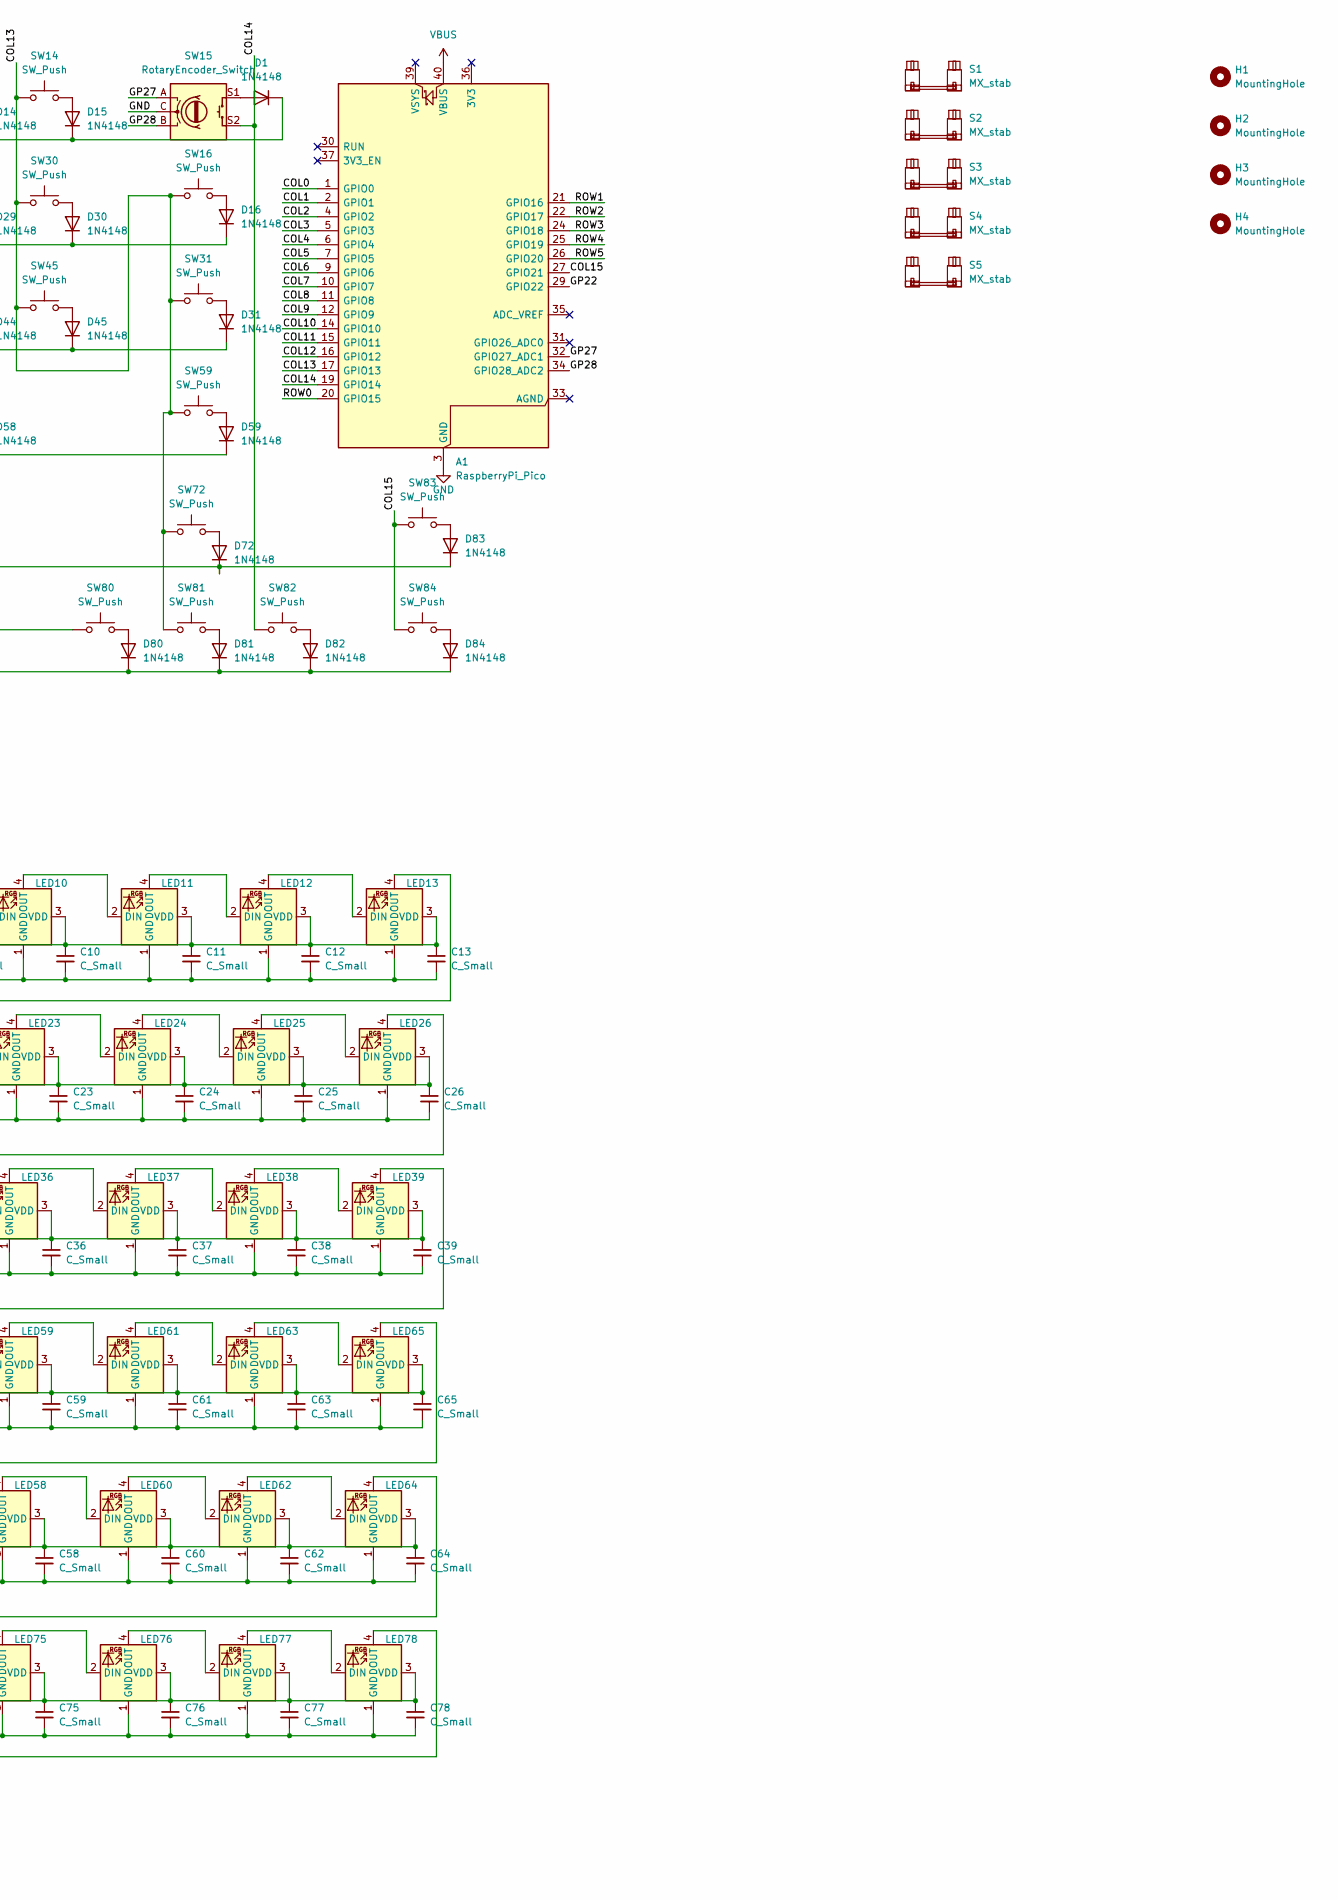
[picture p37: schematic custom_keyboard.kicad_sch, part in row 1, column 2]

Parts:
A1: RaspberryPi_Pico; RaspberryPi_Pico_Common_THT
C1, C2, C3, C4, C5, C6, C7, C8, C9, C10, C11, C12, C13, C14, C15, C16, C17, C18, C19, C20, C21, C22, C23, C24, C25, C26, C27, C28, C29, C30, C31, C32, C33, C34, C35, C36, C37, C38, C39, C40, C41, C42, C43, C44, C45, C46, C47, C48, C49, C50, C51, C52, C53, C54, C55, C56, C57, C58, C59, C60, C61, C62, C63, C64, C65, C66, C67, C68, C69, C70, C71, C72, C73, C74, C75, C76, C77, C78, C79, C80, C81, C82, C83: C_Small; C_0603_1608Metric_Pad1.08x0.95mm_HandSolder
D1, D2, D3, D4, D5, D6, D7, D8, D9, D10, D11, D12, D13, D14, D15, D16, D17, D18, D19, D20, D21, D22, D23, D24, D25, D26, D27, D28, D29, D30, D31, D32, D33, D34, D35, D36, D37, D38, D39, D40, D41, D42, D43, D44, D45, D46, D47, D48, D49, D50, D51, D52, D53, D54, D55, D56, D57, D58, D59, D60, D61, D62, D63, D64, D65, D66, D67, D68, D69, D70, D71, D72, D73, D74, D75, D76, D77, D78, D79, D80, D81, D82, D83, D84: 1N4148; D_DO-35_SOD27_P7.62mm_Horizontal
H1, H2, H3, H4: MountingHole; MountingHole_3.2mm_M3_DIN965_Pad_TopBottom
LED1, LED2, LED3, LED4, LED5, LED6, LED7, LED8, LED9, LED10, LED11, LED12, LED13, LED14, LED15, LED16, LED17, LED18, LED19, LED20, LED21, LED22, LED23, LED24, LED25, LED26, LED27, LED28, LED29, LED30, LED31, LED32, LED33, LED34, LED35, LED36, LED37, LED38, LED39, LED40, LED41, LED42, LED43, LED44, LED45, LED46, LED47, LED48, LED49, LED50, LED51, LED52, LED53, LED54, LED55, LED56, LED57, LED58, LED59, LED60, LED61, LED62, LED63, LED64, LED65, LED66, LED67, LED68, LED69, LED70, LED71, LED72, LED73, LED74, LED75, LED76, LED77, LED78, LED79, LED80, LED81, LED82, LED83: MX_SK6812MINI-E_LCSC; LED_MX_6028R_1
R1, R2: Resistor; R_0805_2012Metric
S1: MX_stab; STAB_MX_2.75u_MODEL
S2, S5: MX_stab; STAB_MX_2.25u_MODEL
S3: MX_stab; STAB_MX_2u_MODEL
S4: MX_stab; STAB_MX_6.25u_MODEL
SW1, SW2, SW3, SW4, SW5, SW6, SW7, SW8, SW9, SW10, SW11, SW12, SW13, SW16, SW17, SW18, SW19, SW20, SW21, SW22, SW23, SW24, SW25, SW26, SW27, SW28, SW29, SW30, SW31, SW33, SW34, SW35, SW36, SW37, SW38, SW39, SW40, SW41, SW42, SW43, SW44, SW47, SW48, SW49, SW50, SW51, SW52, SW53, SW54, SW55, SW56, SW57, SW58, SW59, SW60, SW61, SW62, SW63, SW64, SW65, SW66, SW67, SW68, SW69, SW70, SW71, SW72, SW80, SW81, SW82, SW83, SW84: SW_Push; SW_MX_1u_MODEL
SW14, SW73, SW74, SW75, SW76, SW77, SW78: SW_Push; SW_MX_1.25u_MODEL
SW15: RotaryEncoder_Switch; ROT_Alps_EC11E-Switch
SW32, SW45, SW79: SW_Push; SW_MX_1.5u_MODEL
SW46: SW_Push; SW_MX_1.75u_MODEL

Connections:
/COL0: A1.1 (GPIO0), SW1.1, SW17.1, SW32.1, SW46.1, SW60.1, SW73.1
/COL1: A1.2 (GPIO1), SW2.1, SW18.1, SW33.1, SW47.1, SW61.1, SW74.1
/COL2: A1.4 (GPIO2), SW3.1, SW19.1, SW34.1, SW48.1, SW62.1, SW75.1
/COL3: A1.5 (GPIO3), SW4.1, SW20.1, SW35.1, SW49.1, SW63.1, SW76.1
/COL4: A1.6 (GPIO4), SW5.1, SW21.1, SW36.1, SW50.1, SW64.1
/COL5: A1.7 (GPIO5), SW6.1, SW22.1, SW37.1, SW51.1, SW65.1
/COL6: A1.9 (GPIO6), SW7.1, SW23.1, SW38.1, SW52.1, SW66.1
/COL7: A1.10 (GPIO7), SW8.1, SW24.1, SW39.1, SW53.1, SW67.1
/COL8: A1.11 (GPIO8), SW9.1, SW25.1, SW40.1, SW54.1, SW68.1
/COL9: A1.12 (GPIO9), SW10.1, SW26.1, SW41.1, SW55.1, SW69.1, SW77.1
/COL10: A1.14 (GPIO10), SW11.1, SW27.1, SW42.1, SW56.1, SW70.1, SW78.1
/COL11: A1.15 (GPIO11), SW12.1, SW28.1, SW43.1, SW57.1, SW71.1, SW79.1
/COL12: A1.16 (GPIO12), SW13.1, SW29.1, SW44.1, SW58.1, SW80.1
/COL13: A1.17 (GPIO13), SW14.1, SW16.1, SW30.1, SW31.1, SW45.1, SW59.1, SW72.1, SW81.1
/COL14: A1.19 (GPIO14), SW15.S2, SW82.1
/COL15: A1.27 (GPIO21), SW83.1, SW84.1
/GP22: A1.29 (GPIO22), R1.1
/GP27: A1.32 (GPIO27_ADC1), SW15.A
/GP28: A1.34 (GPIO28_ADC2), SW15.B
/ROW0: A1.20 (GPIO15), D1.1 (K), D2.1 (K), D3.1 (K), D4.1 (K), D5.1 (K), D6.1 (K), D7.1 (K), D8.1 (K), D9.1 (K), D10.1 (K), D11.1 (K), D12.1 (K), D13.1 (K), D14.1 (K), D15.1 (K)
/ROW1: A1.21 (GPIO16), D16.1 (K), D17.1 (K), D18.1 (K), D19.1 (K), D20.1 (K), D21.1 (K), D22.1 (K), D23.1 (K), D24.1 (K), D25.1 (K), D26.1 (K), D27.1 (K), D28.1 (K), D29.1 (K), D30.1 (K)
/ROW2: A1.22 (GPIO17), D31.1 (K), D32.1 (K), D33.1 (K), D34.1 (K), D35.1 (K), D36.1 (K), D37.1 (K), D38.1 (K), D39.1 (K), D40.1 (K), D41.1 (K), D42.1 (K), D43.1 (K), D44.1 (K), D45.1 (K)
/ROW3: A1.24 (GPIO18), D46.1 (K), D47.1 (K), D48.1 (K), D49.1 (K), D50.1 (K), D51.1 (K), D52.1 (K), D53.1 (K), D54.1 (K), D55.1 (K), D56.1 (K), D57.1 (K), D58.1 (K), D59.1 (K)
/ROW4: A1.25 (GPIO19), D60.1 (K), D61.1 (K), D62.1 (K), D63.1 (K), D64.1 (K), D65.1 (K), D66.1 (K), D67.1 (K), D68.1 (K), D69.1 (K), D70.1 (K), D71.1 (K), D72.1 (K), D83.1 (K)
/ROW5: A1.26 (GPIO20), D73.1 (K), D74.1 (K), D75.1 (K), D76.1 (K), D77.1 (K), D78.1 (K), D79.1 (K), D80.1 (K), D81.1 (K), D82.1 (K), D84.1 (K)
GND: A1.3 (GND), A1.8 (GND), A1.13 (GND), A1.18 (GND), A1.23 (GND), A1.28 (GND), A1.38 (GND), C1.2, C2.2, C3.2, C4.2, C5.2, C6.2, C7.2, C8.2, C9.2, C10.2, C11.2, C12.2, C13.2, C14.2, C15.2, C16.2, C17.2, C18.2, C19.2, C20.2, C21.2, C22.2, C23.2, C24.2, C25.2, C26.2, C27.2, C28.2, C29.2, C30.2, C31.2, C32.2, C33.2, C34.2, C35.2, C36.2, C37.2, C38.2, C39.2, C40.2, C41.2, C42.2, C43.2, C44.2, C45.2, C46.2, C47.2, C48.2, C49.2, C50.2, C51.2, C52.2, C53.2, C54.2, C55.2, C56.2, C57.2, C58.2, C59.2, C60.2, C61.2, C62.2, C63.2, C64.2, C65.2, C66.2, C67.2, C68.2, C69.2, C70.2, C71.2, C72.2, C73.2, C74.2, C75.2, C76.2, C77.2, C78.2, C79.2, C80.2, C81.2, C82.2, C83.2, LED1.1 (GND), LED2.1 (GND), LED3.1 (GND), LED4.1 (GND), LED5.1 (GND), LED6.1 (GND), LED7.1 (GND), LED8.1 (GND), LED9.1 (GND), LED10.1 (GND), LED11.1 (GND), LED12.1 (GND), LED13.1 (GND), LED14.1 (GND), LED15.1 (GND), LED16.1 (GND), LED17.1 (GND), LED18.1 (GND), LED19.1 (GND), LED20.1 (GND), LED21.1 (GND), LED22.1 (GND), LED23.1 (GND), LED24.1 (GND), LED25.1 (GND), LED26.1 (GND), LED27.1 (GND), LED28.1 (GND), LED29.1 (GND), LED30.1 (GND), LED31.1 (GND), LED32.1 (GND), LED33.1 (GND), LED34.1 (GND), LED35.1 (GND), LED36.1 (GND), LED37.1 (GND), LED38.1 (GND), LED39.1 (GND), LED40.1 (GND), LED41.1 (GND), LED42.1 (GND), LED43.1 (GND), LED44.1 (GND), LED45.1 (GND), LED46.1 (GND), LED47.1 (GND), LED48.1 (GND), LED49.1 (GND), LED50.1 (GND), LED51.1 (GND), LED52.1 (GND), LED53.1 (GND), LED54.1 (GND), LED55.1 (GND), LED56.1 (GND), LED57.1 (GND), LED58.1 (GND), LED59.1 (GND), LED60.1 (GND), LED61.1 (GND), LED62.1 (GND), LED63.1 (GND), LED64.1 (GND), LED65.1 (GND), LED66.1 (GND), LED67.1 (GND), LED68.1 (GND), LED69.1 (GND), LED70.1 (GND), LED71.1 (GND), LED72.1 (GND), LED73.1 (GND), LED74.1 (GND), LED75.1 (GND), LED76.1 (GND), LED77.1 (GND), LED78.1 (GND), LED79.1 (GND), LED80.1 (GND), LED81.1 (GND), LED82.1 (GND), LED83.1 (GND), SW15.C
unnamed: D1.2 (A), SW15.S1
unnamed: D2.2 (A), SW1.2
unnamed: D3.2 (A), SW2.2
unnamed: D4.2 (A), SW3.2
unnamed: D5.2 (A), SW4.2
unnamed: D6.2 (A), SW5.2
unnamed: D7.2 (A), SW6.2
unnamed: D8.2 (A), SW7.2
unnamed: D9.2 (A), SW8.2
unnamed: D10.2 (A), SW9.2
unnamed: D11.2 (A), SW10.2
unnamed: D12.2 (A), SW11.2
unnamed: D13.2 (A), SW12.2
unnamed: D14.2 (A), SW13.2
unnamed: D15.2 (A), SW14.2
unnamed: D16.2 (A), SW16.2
unnamed: D17.2 (A), SW17.2
unnamed: D18.2 (A), SW18.2
unnamed: D19.2 (A), SW19.2
unnamed: D20.2 (A), SW20.2
unnamed: D21.2 (A), SW21.2
unnamed: D22.2 (A), SW22.2
unnamed: D23.2 (A), SW23.2
unnamed: D24.2 (A), SW24.2
unnamed: D25.2 (A), SW25.2
unnamed: D26.2 (A), SW26.2
unnamed: D27.2 (A), SW27.2
unnamed: D28.2 (A), SW28.2
unnamed: D29.2 (A), SW29.2
unnamed: D30.2 (A), SW30.2
unnamed: D31.2 (A), SW31.2
unnamed: D32.2 (A), SW32.2
unnamed: D33.2 (A), SW33.2
unnamed: D34.2 (A), SW34.2
unnamed: D35.2 (A), SW35.2
unnamed: D36.2 (A), SW36.2
unnamed: D37.2 (A), SW37.2
unnamed: D38.2 (A), SW38.2
unnamed: D39.2 (A), SW39.2
unnamed: D40.2 (A), SW40.2
unnamed: D41.2 (A), SW41.2
unnamed: D42.2 (A), SW42.2
unnamed: D43.2 (A), SW43.2
unnamed: D44.2 (A), SW44.2
unnamed: D45.2 (A), SW45.2
unnamed: D46.2 (A), SW46.2
unnamed: D47.2 (A), SW47.2
unnamed: D48.2 (A), SW48.2
unnamed: D49.2 (A), SW49.2
unnamed: D50.2 (A), SW50.2
unnamed: D51.2 (A), SW51.2
unnamed: D52.2 (A), SW52.2
unnamed: D53.2 (A), SW53.2
unnamed: D54.2 (A), SW54.2
unnamed: D55.2 (A), SW55.2
unnamed: D56.2 (A), SW56.2
unnamed: D57.2 (A), SW57.2
unnamed: D58.2 (A), SW58.2
unnamed: D59.2 (A), SW59.2
unnamed: D60.2 (A), SW60.2
unnamed: D61.2 (A), SW61.2
unnamed: D62.2 (A), SW62.2
unnamed: D63.2 (A), SW63.2
unnamed: D64.2 (A), SW64.2
unnamed: D65.2 (A), SW65.2
unnamed: D66.2 (A), SW66.2
unnamed: D67.2 (A), SW67.2
unnamed: D68.2 (A), SW68.2
unnamed: D69.2 (A), SW69.2
unnamed: D70.2 (A), SW70.2
unnamed: D71.2 (A), SW71.2
unnamed: D72.2 (A), SW72.2
unnamed: D73.2 (A), SW73.2
unnamed: D74.2 (A), SW74.2
unnamed: D75.2 (A), SW75.2
unnamed: D76.2 (A), SW76.2
unnamed: D77.2 (A), SW77.2
unnamed: D78.2 (A), SW78.2
unnamed: D79.2 (A), SW79.2
unnamed: D80.2 (A), SW80.2
unnamed: D81.2 (A), SW81.2
unnamed: D82.2 (A), SW82.2
unnamed: D83.2 (A), SW83.2
unnamed: D84.2 (A), SW84.2
unnamed: LED1.2 (DIN), R1.2
unnamed: LED1.4 (DOUT), LED2.2 (DIN)
unnamed: LED2.4 (DOUT), LED3.2 (DIN)
unnamed: LED3.4 (DOUT), LED4.2 (DIN)
unnamed: LED4.4 (DOUT), LED5.2 (DIN)
unnamed: LED5.4 (DOUT), LED6.2 (DIN)
unnamed: LED6.4 (DOUT), LED7.2 (DIN)
unnamed: LED7.4 (DOUT), LED8.2 (DIN)
unnamed: LED8.4 (DOUT), LED9.2 (DIN)
unnamed: LED9.4 (DOUT), LED10.2 (DIN)
unnamed: LED10.4 (DOUT), LED11.2 (DIN)
unnamed: LED11.4 (DOUT), LED12.2 (DIN)
unnamed: LED12.4 (DOUT), LED13.2 (DIN)
unnamed: LED13.4 (DOUT), LED14.2 (DIN)
unnamed: LED14.4 (DOUT), LED15.2 (DIN)
unnamed: LED15.4 (DOUT), LED16.2 (DIN)
unnamed: LED16.4 (DOUT), LED17.2 (DIN)
unnamed: LED17.4 (DOUT), LED18.2 (DIN)
unnamed: LED18.4 (DOUT), LED19.2 (DIN)
unnamed: LED19.4 (DOUT), LED20.2 (DIN)
unnamed: LED20.4 (DOUT), LED21.2 (DIN)
unnamed: LED21.4 (DOUT), LED22.2 (DIN)
unnamed: LED22.4 (DOUT), LED23.2 (DIN)
unnamed: LED23.4 (DOUT), LED24.2 (DIN)
unnamed: LED24.4 (DOUT), LED25.2 (DIN)
unnamed: LED25.4 (DOUT), LED26.2 (DIN)
unnamed: LED26.4 (DOUT), LED27.2 (DIN)
unnamed: LED27.4 (DOUT), LED28.2 (DIN)
unnamed: LED28.4 (DOUT), LED29.2 (DIN)
unnamed: LED29.4 (DOUT), LED30.2 (DIN)
unnamed: LED30.4 (DOUT), LED31.2 (DIN)
unnamed: LED31.4 (DOUT), LED32.2 (DIN)
unnamed: LED32.4 (DOUT), LED33.2 (DIN)
unnamed: LED33.4 (DOUT), LED34.2 (DIN)
unnamed: LED34.4 (DOUT), LED35.2 (DIN)
unnamed: LED35.4 (DOUT), LED36.2 (DIN)
unnamed: LED36.4 (DOUT), LED37.2 (DIN)
unnamed: LED37.4 (DOUT), LED38.2 (DIN)
unnamed: LED38.4 (DOUT), LED39.2 (DIN)
unnamed: LED39.4 (DOUT), LED41.2 (DIN)
unnamed: LED40.2 (DIN), LED65.4 (DOUT)
unnamed: LED40.4 (DOUT), LED42.2 (DIN)
unnamed: LED41.4 (DOUT), LED43.2 (DIN)
unnamed: LED42.4 (DOUT), LED44.2 (DIN)
unnamed: LED43.4 (DOUT), LED45.2 (DIN)
unnamed: LED44.4 (DOUT), LED46.2 (DIN)
unnamed: LED45.4 (DOUT), LED47.2 (DIN)
unnamed: LED46.4 (DOUT), LED48.2 (DIN)
unnamed: LED47.4 (DOUT), LED49.2 (DIN)
unnamed: LED48.4 (DOUT), LED50.2 (DIN)
unnamed: LED49.4 (DOUT), LED51.2 (DIN)
unnamed: LED50.4 (DOUT), LED52.2 (DIN)
unnamed: LED51.4 (DOUT), LED53.2 (DIN)
unnamed: LED52.4 (DOUT), LED54.2 (DIN)
unnamed: LED53.4 (DOUT), LED55.2 (DIN)
unnamed: LED54.4 (DOUT), LED56.2 (DIN)
unnamed: LED55.4 (DOUT), LED57.2 (DIN)
unnamed: LED56.4 (DOUT), LED58.2 (DIN)
unnamed: LED57.4 (DOUT), LED59.2 (DIN)
unnamed: LED58.4 (DOUT), LED60.2 (DIN)
unnamed: LED59.4 (DOUT), LED61.2 (DIN)
unnamed: LED60.4 (DOUT), LED62.2 (DIN)
unnamed: LED61.4 (DOUT), LED63.2 (DIN)
unnamed: LED62.4 (DOUT), LED64.2 (DIN)
unnamed: LED63.4 (DOUT), LED65.2 (DIN)
unnamed: LED64.4 (DOUT), LED66.2 (DIN)
unnamed: LED66.4 (DOUT), LED67.2 (DIN)
unnamed: LED67.4 (DOUT), LED68.2 (DIN)
unnamed: LED68.4 (DOUT), LED69.2 (DIN)
unnamed: LED69.4 (DOUT), LED70.2 (DIN)
unnamed: LED70.4 (DOUT), LED71.2 (DIN)
unnamed: LED71.4 (DOUT), LED72.2 (DIN)
unnamed: LED72.4 (DOUT), LED73.2 (DIN)
unnamed: LED73.4 (DOUT), LED74.2 (DIN)
unnamed: LED74.4 (DOUT), LED75.2 (DIN)
unnamed: LED75.4 (DOUT), LED76.2 (DIN)
unnamed: LED76.4 (DOUT), LED77.2 (DIN)
unnamed: LED77.4 (DOUT), LED78.2 (DIN)
unnamed: LED78.4 (DOUT), LED79.2 (DIN)
unnamed: LED79.4 (DOUT), LED80.2 (DIN)
unnamed: LED80.4 (DOUT), LED81.2 (DIN)
unnamed: LED81.4 (DOUT), LED82.2 (DIN)
unnamed: LED82.4 (DOUT), LED83.2 (DIN)
unnamed: LED83.4 (DOUT), R2.1
VBUS: A1.40 (VBUS), C1.1, C2.1, C3.1, C4.1, C5.1, C6.1, C7.1, C8.1, C9.1, C10.1, C11.1, C12.1, C13.1, C14.1, C15.1, C16.1, C17.1, C18.1, C19.1, C20.1, C21.1, C22.1, C23.1, C24.1, C25.1, C26.1, C27.1, C28.1, C29.1, C30.1, C31.1, C32.1, C33.1, C34.1, C35.1, C36.1, C37.1, C38.1, C39.1, C40.1, C41.1, C42.1, C43.1, C44.1, C45.1, C46.1, C47.1, C48.1, C49.1, C50.1, C51.1, C52.1, C53.1, C54.1, C55.1, C56.1, C57.1, C58.1, C59.1, C60.1, C61.1, C62.1, C63.1, C64.1, C65.1, C66.1, C67.1, C68.1, C69.1, C70.1, C71.1, C72.1, C73.1, C74.1, C75.1, C76.1, C77.1, C78.1, C79.1, C80.1, C81.1, C82.1, C83.1, LED1.3 (VDD), LED2.3 (VDD), LED3.3 (VDD), LED4.3 (VDD), LED5.3 (VDD), LED6.3 (VDD), LED7.3 (VDD), LED8.3 (VDD), LED9.3 (VDD), LED10.3 (VDD), LED11.3 (VDD), LED12.3 (VDD), LED13.3 (VDD), LED14.3 (VDD), LED15.3 (VDD), LED16.3 (VDD), LED17.3 (VDD), LED18.3 (VDD), LED19.3 (VDD), LED20.3 (VDD), LED21.3 (VDD), LED22.3 (VDD), LED23.3 (VDD), LED24.3 (VDD), LED25.3 (VDD), LED26.3 (VDD), LED27.3 (VDD), LED28.3 (VDD), LED29.3 (VDD), LED30.3 (VDD), LED31.3 (VDD), LED32.3 (VDD), LED33.3 (VDD), LED34.3 (VDD), LED35.3 (VDD), LED36.3 (VDD), LED37.3 (VDD), LED38.3 (VDD), LED39.3 (VDD), LED40.3 (VDD), LED41.3 (VDD), LED42.3 (VDD), LED43.3 (VDD), LED44.3 (VDD), LED45.3 (VDD), LED46.3 (VDD), LED47.3 (VDD), LED48.3 (VDD), LED49.3 (VDD), LED50.3 (VDD), LED51.3 (VDD), LED52.3 (VDD), LED53.3 (VDD), LED54.3 (VDD), LED55.3 (VDD), LED56.3 (VDD), LED57.3 (VDD), LED58.3 (VDD), LED59.3 (VDD), LED60.3 (VDD), LED61.3 (VDD), LED62.3 (VDD), LED63.3 (VDD), LED64.3 (VDD), LED65.3 (VDD), LED66.3 (VDD), LED67.3 (VDD), LED68.3 (VDD), LED69.3 (VDD), LED70.3 (VDD), LED71.3 (VDD), LED72.3 (VDD), LED73.3 (VDD), LED74.3 (VDD), LED75.3 (VDD), LED76.3 (VDD), LED77.3 (VDD), LED78.3 (VDD), LED79.3 (VDD), LED80.3 (VDD), LED81.3 (VDD), LED82.3 (VDD), LED83.3 (VDD)

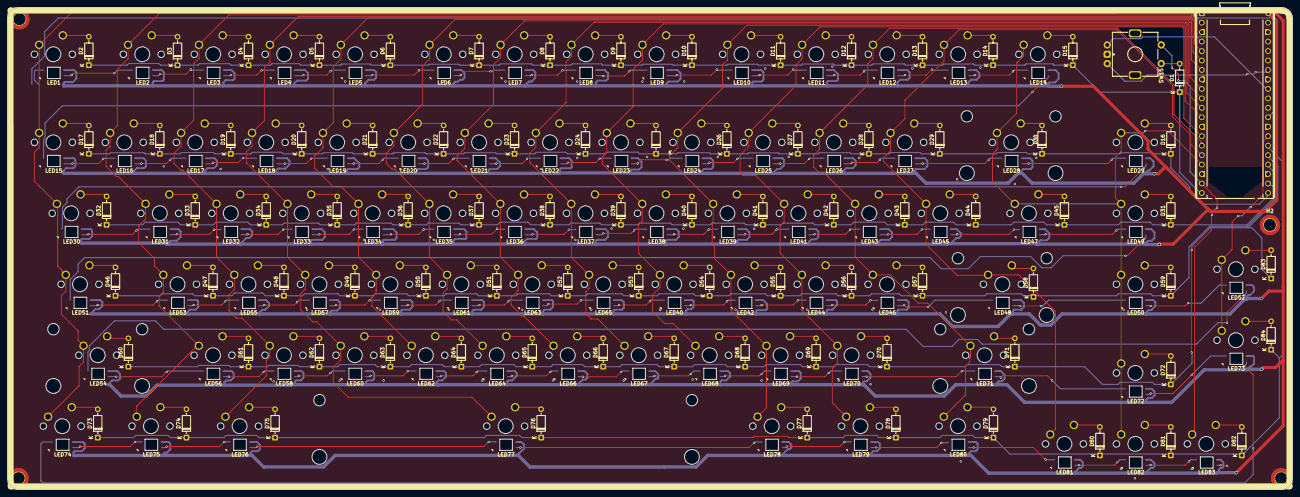
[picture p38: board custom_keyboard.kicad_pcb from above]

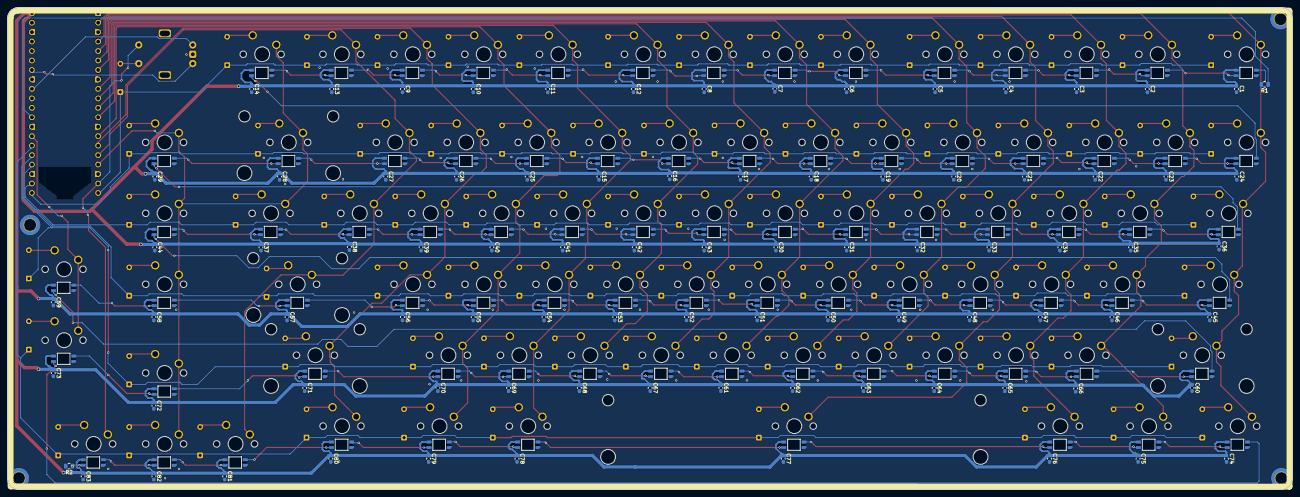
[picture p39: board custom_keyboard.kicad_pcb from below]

Board: 2 copper layers, 345.0 x 129.4 mm, 346 parts (85 on the bottom side), 195 nets.

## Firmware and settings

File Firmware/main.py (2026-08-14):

print("Starting")

import board

from kmk.kmk_keyboard import KMKKeyboard
from kmk.keys import KC
from kmk.scanners import DiodeOrientation
from kmk.handlers.sequences import simple_key_sequence
from kmk.modules.layers import Layers
from kmk.extensions.rgb import RGB
from kmk.modules.encoder import EncoderHandler

keyboard = KMKKeyboard()

keyboard.col_pins = (board.GP0, board.GP01, board.GP02, board.GP03, board.GP04, board.GP05, board.GP06, board.GP07, board.GP08, board.GP09, board.GP10, board.GP11, board.GP12, board.GP13, board.GP14, board.GP21)
keyboard.row_pins = (board.GP15, board.GP16, board.GP17, board.GP18, board.GP19, board.GP20,)
keyboard.diode_orientation = DiodeOrientation.COL2ROW

encoder_handler = EncoderHandler()

keyboard.modules.append(Layers())
keyboard.modules.append(encoder_handler)

encoder_handler.pins = ((board.GP27, board.GP28, None))

rgb = RGB(pixel_pin=board.GP22, num_pixels=83, rgb_oder=(1,0,2), val_default=40, val_limit = 60)
keyboard.extensions.append(rgb)

LED = KC.LT(1)

## For calculator macro to work you need to create a shortcut with these keys that runs %WinDir%\System32\calc.exe
## For Windows devices
calc_macro = simple_key_sequence(
    (
        KC.LCTL(KC.LALT)(KC.C)
    )
)

screen_shot_macro = simple_key_sequence(
    (
        KC.WIN(KC.LSHIFT)(KC.S)
    )
)

save_macro = simple_key_sequence(
    (
        KC.LCTRl(KC.S)
    )
)

keyboard.keymap = [
    [ ## Base layer
     KC.ESC,  KC.F1,  KC.F2, KC.F3, KC.F4,
     KC.F5, KC.F6, KC.F7, KC.F8, KC.F9,
     KC.F10, KC.F11, KC.F12, calc_macro, KC.MPLY,
     KC.GRV, KC.N1, KC.N2, KC.N3, KC.N4,
     KC.N5, KC.N6, KC.N7, KC.N8, KC.N9,
     KC.N0, KC.MINUS, KC.EQUAL, KC.BSPC, KC.DEL,
     KC.TAB, KC.Q, KC.W, KC.E, KC.R,
     KC.T, KC.Y, KC.U, KC.I, KC.O,
     KC.P, KC.LBRC, KC.RBRC, KC.BSLS, KC.PGUP, KC.CAPSLOCK,
     KC.A, KC.S, KC.D, KC.F, KC.G,
     KC.H, KC.J, KC.K, KC.L, KC.SCLN,
     KC.QUOTE, KC.ENT, KC.PGDN, KC.LSHIFT, KC.Z,
     KC.X, KC.C, KC.V, KC.B, KC.N,
     KC.M, KC.COMM, KC.PERIOD, KC.SLASH, KC.RSHIFT,
     KC.UP, screen_shot_macro, KC.LCTRL, KC.WIN, KC.LALT, 
     KC.SPC, KC.RALT, KC.RFN, KC.RCTRL, KC.LEFT,
     KC.DOWN, KC.RIGHT, save_macro,
    ],

    [ ## LED
        KC.TRNS,  KC.TRNS,  KC.TRNS, KC.TRNS, KC.TRNS,
         KC.TRNS, KC.TRNS, KC.TRNS, KC.TRNS, KC.TRNS,
         KC.TRNS, KC.TRNS, KC.TRNS, KC.TRNS, KC.MTRNSPLY,
         KC.TRNS, KC.TRNS, KC.TRNS, KC.TRNS, KC.TRNS,
         KC.TRNS, KC.TRNS, KC.TRNS, KC.TRNS, KC.TRNS,
         KC.TRNS, KC.TRNS, KC.TRNS, KC.TRNS, KC.TRNS,
         KC.TRNS, KC.TRNS, KC.TRNS, KC.TRNS, KC.TRNS,
         KC.TRNS, KC.TRNS, KC.TRNS, KC.TRNS, KC.TRNS,
         KC.TRNS, KC.TRNS, KC.TRNS, KC.TRNS, KC.TRNS, KC.TRNS,
         KC.TRNS, KC.TRNSS, KC.TRNS, KC.TRNS, KC.TRNS,
         KC.TRNS, KC.TRNS, KC.TRNS, KC.TRNS, KC.TRNS,
         KC.TRNS, KC.TRNS, KC.TRNS, KC.TRNS, KC.TRNS,
         KC.TRNS, KC.TRNS, KC.TRNS, KC.TRNS, KC.TRNS,
         KC.TRNS, KC.TRNS, KC.TRNS, KC.TRNS, KC.TRNS,
         KC.RGB_VAI(), KC.RGB_MODE_PLAIN(), KC.TRNS, KC.TRNS, KC.TRNS, 
         KC.TRNS, KC.TRNS, KC.TRNS, KC.TRNS, KC.RGB_AND(),
         KC.RGB_VAD(), KC.RGB_ANI(), KC.RGB_TOG(),
        ]
]

encoder_handler.map = [
            ((KC.VOLD, KC.VOLU),),            
            ]

if __name__ == '__main__':
    keyboard.go()

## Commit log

2026-07-04 Rename Schematic.md to 1. Schematic.md
2026-07-04 Update and rename 1. Schematic.md to 2. Schematic.md
2026-07-04 Rename final layout wiring.png to matrix_wiring.png
2026-07-04 Update 2. Schematic.md
    Added images
2026-07-04 Update 2. Schematic.md
    Fixed schematic image directory
2026-07-05 Create 3. PCB.md
2026-07-05 Update 3. PCB.md
2026-07-06 Update 3. PCB.md
    corrected amount of time worked
2026-07-06 Update 3. PCB.md
    Ran drc and fixed warnings
2026-08-09 Create Making the Case.md
2026-08-09 Update and rename Making the Case.md to 7. Case.md
2026-08-09 Update 7. Case.md
2026-08-09 Create 8. Fixing the PCB.md
2026-08-13 Update 8. Fixing the PCB.md
2026-08-15 Create BOM
2026-08-15 Rename Mechanical Keyboard BOM - Sheet1.csv to BOM - Sheet1.csv
    [BOM - Sheet1.csv]
2026-08-15 Rename Mechanical Keyboard BOM - Sheet1.pdf to BOM.pdf
2026-08-15 Rename BOM - Sheet1.csv to BOM.csv
    [BOM.csv]
2026-08-15 Create 10. Making the BOM.md
2026-08-15 Update 10. Making the BOM.md
2026-08-16 Rename Stabilizer - close.STEP to Stabilizer.STEP
    [Stabilizer.STEP]
2026-08-16 Rename Stabilizer_Cherry_MX_6.25u.stp to Stabilizer 6.25u.stp
    [Stabilizer 6.25u.stp]
2026-08-16 Rename Stabilizer.STEP to Stabilizer 2u.STEP
    [Stabilizer 2u.STEP]
2026-08-16 Update 2. Schematic.md
2026-10-04 Rename custom_keyboard_V2 (1).zip to gerbers.zip
2026-10-23 Rename Mechanical Keyboard BOM - Sheet1.csv to BOM.csv
